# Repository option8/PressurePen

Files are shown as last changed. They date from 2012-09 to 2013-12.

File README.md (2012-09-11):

PressurePen
===========

Documentation and instructions for the open source hardware PressurePen project. The PressurePen is a pressure sensitive stylus for iPad and Android tablets that connects via a standard audio jack.

From FreedomDefined.org:

	Open source hardware is hardware whose design is made publicly available so that anyone can study, modify, distribute, make, and sell the design or hardware based on that design.

All hardware and specifications of the PressurePen are licensed under the TAPR OHL (see tapr.org/OHL). In summary, the license states:

	You may modify the documentation and make products based upon it.
	You may use products for any legal purpose without limitation.
	You may distribute unmodified documentation, but you must include the complete package as you received it.
	You may distribute products you make to third parties, if you either include the documentation on which the product is based, or make it available without charge for at least three years to anyone who requests it.
	You may distribute modified documentation or products based on it, if you:
	Include those modifications, following the requirements stated below.
	Attempt to send the modified documentation by email to any of the developers who have provided their email address. This is a good faith obligation -- if the email fails, you need do nothing more and may go on with your distribution.
	License your modifications under the OHL.

The full license text is here: http://www.tapr.org/TAPR_Open_Hardware_License_v1.0.txt

For 3D parts, see:
	http://www.thingiverse.com/option8
	
For sample application code, see:
	https://github.com/option8/PressurePaint
	
To order a kit or complete PressurePen, go to:
	http://pressurepen.us

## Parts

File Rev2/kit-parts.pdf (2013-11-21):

## For assembly instructions, go to https://www.tindie.com/products/option8/pressurepen-kit/

## These parts are included in your PressurePen Hacker Edition kit:

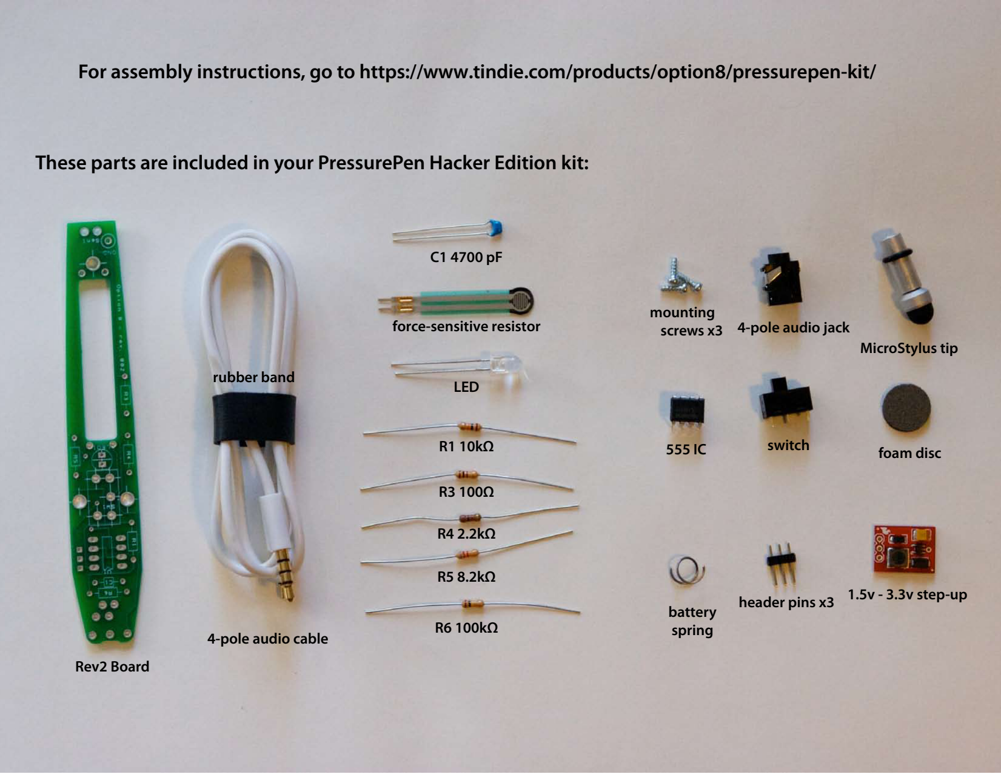
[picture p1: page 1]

Rev2 Board

switch

4-pole audio jack

mounting
screws x3
MicroStylus tip

foam disc

header pins x3 battery
spring 4-pole audio cable

rubber band

1.5v - 3.3v step-up

R1 10kΩ | 555 IC

R3 100Ω

R4 2.2kΩ

R5 8.2kΩ

R6 100kΩ

C1 4700 pF

LED

force-sensitive resistor

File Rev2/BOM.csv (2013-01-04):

Digi-Key Part Number | Description | Quantity | Manufacturer | Manufacturer Part Number
SW101-ND | SWITCH SLIDE SPDT 0.5A BLACK | 1 | CW INDUSTRIES | G-107-0513
CP-43514-ND | CONN 3.5MM AUDIO JACK 4 COND PCB | 1 | CUI INC | SJ-43514
1027-1000-ND | SENSOR FSR400 0.2" CIRC W/TAB | 1 | INTERLINK ELECTRONICS | 30-49649
296-1857-5-ND | IC OSC MONO TIMING 2.1MHZ 8-DIP | 1 | TEXAS INSTRUMENTS | TLC555CP
754-1273-ND | LED SS 5MM 568NM GREEN WATER CLR | 1 | KINGBRIGHT CORP | WP7113SGC
490-3844-ND | CAP CER 4700PF 50V 10% RADIAL | 1 | MURATA ELECTRONICS | RPER71H472K2P1A03B
8.2KQBK-ND | RES 8.2K OHM 1/4W 5% CARBON FILM | 1 | YAGEO | CFR-25JB-52-8K2
10KQBK-ND | RES 10K OHM 1/4W 5% CARBON FILM | 1 | YAGEO | CFR-25JB-52-10K
100KQBK-ND | RES 100K OHM 1/4W 5% CARBON FILM | 1 | YAGEO | CFR-25JB-52-100K
2.2KQBK-ND | RES 2.2K OHM 1/4W 5% CARBON FILM | 1 | YAGEO | CFR-25JB-52-2K2
100QBK-ND | RES 100 OHM 1/4W 5% CARBON FILM | 1 | YAGEO | CFR-25JB-52-100R
3429K-ND | SPACER RND #6SCREW .625"L ALUM | 1 | KEYSTONE ELECTRONICS | 3429
McMaster Carr Part Number
99397A314 | 6mm Torx (T5) M2 size screws | 3
92510A446 | Aluminum Unthreaded Spacer 1/4" OD, 5/8" Length, #6 Screw Size – ALT FOR DIGIKEY PART ABOVE | 1
SparkFun Part Number
PRT-10967 | NCP1402-3.3V Step-Up Breakout | 1
MicroStylus
 | MicroStylus Jack | 1
Amazon Supply
B005282S4G | 001-1/2 Buna-N O-Ring, 70A Durometer, Round, Black, 1/16" ID, 1/8" OD, 1/32" Width (Pack of 100) | 1
B001D8A3IM | 006 EPDM O-Ring, 70A Durometer, Black, 1/8" ID, 1/4" OD, 1/16" Width (Pack of 100) | 1
B005KUFNCK | Music Wire Compression Spring, Steel, Inch, 0.30" OD, 0.03" Wire Size | 1
Misc
 | conductive silicone foam .0625'' thickness | .5'' circle | Rogers Corp | EC2130
 | Header Pins, .1'' pitch, 11.5mm length | 3
 | Rubber band, 1'' x .5'' x .04'' | 1 | Aero Rubber Co
 | 4-pole 3.5mm audio cable, male-male | 1
 | Double-sided tape
 | Lead-free solder

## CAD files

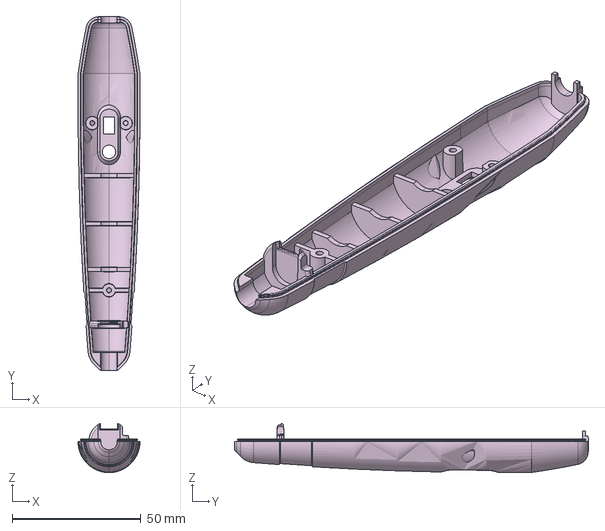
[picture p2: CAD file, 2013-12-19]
Rev2/shell/OP8_body_r12c_AA-Final.stp
24.1 x 137.6 x 19.2 mm

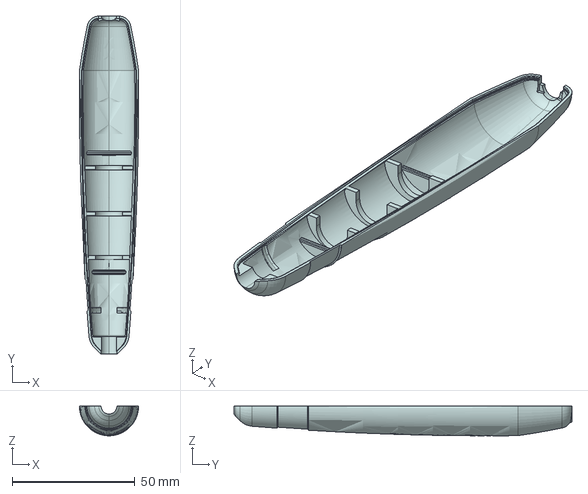
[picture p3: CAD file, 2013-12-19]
Rev2/shell/OP8_body_r12c_AB-Final.stp
24.0 x 137.5 x 12.1 mm

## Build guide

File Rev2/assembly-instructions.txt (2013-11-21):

Kit assembly instructions:

Open package and check contents. 

Last edit: 10.24.2012

1: Step-up board

For the following steps, you will need:
	soldering iron
	solder (preferably lead-free)
	
Locate the header pins (3) and 1.5v-3.3v step-up board (1).

With the flat side of the step-up board (the side with the OSHW logo) facing down, insert the short end of the header pins into the 3 holes.

Using a third hand, alligator clip or hemostat, hold the pins in place and flip the board over. Solder the pins in place as shown.

Set the step-up board aside.

2: Battery clips

For the following steps, you will need:
	soldering iron
	wire snips
	needle-nosed pliers
	
Locate the battery spring. 

With wire snips, cut the spring into two pieces as shown. You should be left with one spring with about one full loop, and a slightly longer spring.

You will be working on both sides of the PCB during assembly. The side with the resistor locations printed on it will be referred to as the “resistor side”, the other side, with “AAA” printed on it will be the “battery side”.

Looking at the “resistor” side of the board, thread the longer spring through the negative/ground holes. The negative end of the battery cutout is near the narrower end of the board. Repeat with the smaller spring and the positive end of the battery cutout. 

Before you solder these in place, test your fit with a AAA battery (not included). It should fit snugly between the springs and be held there by the tension on them on the “battery” side of the board. It may be necessary to remove another loop of make some bends in the springs to fit. The battery will sit on top of the cutout, on the battery side of the board. Once you're happy with the fit, solder the springs in place.

Turn the board over and clip any length of spring that pokes through. This may interfere with other components, or with assembly later.

3: Resistors

For the following steps, you will need:
	soldering iron
	wire snips
	alligator clips, hemostat, "third hand"
	tape
	double-sided tape

Locate the five resistors in your kit. You should have:
R1 10kΩ – brown-black-orange
R3 100Ω – brown-black-brown
R4 2.2kΩ – red-red-red
R5 8.2kΩ – grey-red-red*
R6 100kΩ – brown-black-yellow
(on the Rev2 board, there is no R2)

Bend the leads on the resistor, and thread them through the hole, so the body of the resistor is snug against the resistor side of the board. There is no polarity to these, so they can go in either direction. It helps to bend the leads outward again once you thread them through the hole, to hold the resistor in place while you solder it from the other side of the board.

Solder the leads to the board. Snip the extra length off. Save one of the leads for a later step. The others can be discarded.

Repeat with all five resistors.

* The 8.2kΩ resistor connects in-line with the LED. This reduces the brightness of the LED and its drain on the battery. If you desire a brighter indicator, you can replace the 8.2kΩ resistor with one of a smaller value.
4: Capacitor

Locate the capacitor in your kit. It's the small, blue thing that's not a resistor and not an LED.

As with the resistors, bend the leads of the capacitor to fit through the holes in the board and solder in place. Again, this capacitor has no polarity, so it can go in either direction.

5: LED

Locate the LED in your kit. LEDs have a specific polarity, so notice the length of the leads. The shorter leg corresponds with a flat spot on the side of the LED base. The shorter leg and flat side should line up with the flat side of the LED label on the board. Thread the legs through and double-check that the flat side of the LED lines up with the flat side of the label. The LED should also be snug to the board itself, or it may interfere with the shell when assembled.

Solder the leads to the board. Snip off the extra length and discard.

6: Switch

Locate the switch in your kit.

The switch will only fit on the board in one direction. On the Rev2 board, there will be seven holes, though the switch only needs five. The leads are short, so you may need to tape or clip the switch in place on the board while you solder the leads to the board from the battery side. The switch should also be snug to the board itself, or it may interfere with the shell when assembled.

Solder the five leads to the board. Be sure that these joints are solid, as the switch will be taking some mechanical stress from turning the PressurePen on and off.

7: 555 timer chip

Locate the 555 Integrated Circuit (IC) in your kit.

Notice that there's a small dot in one corner of the IC. This corresponds to pin #1. This dot should be on the same end of the IC as the notch in the printed diagram on the circuit board. Line up the dot and the notch and push the eight leads through the board. You may need to squeeze or bend the leads on the chip to fit through.

Before you solder, check to be sure the dot on the IC is nearest the wider end of the PressurePen board.

Once in place, you may again need to tape or clip the IC to the board to solder from the other side.

Solder the eight leads in place.

8: Audio jack

Locate the audio jack in your kit. 

Turn over the circuit board. You should now be looking at the battery side. At the wide end of the board, there is a small notch and seven holes marked CJ1. This will line up with the barrel of the audio jack, its four leads and small plastic posts. The jack should only fit one way on the board, the round part of the barrel sitting in the notch on the board.

Again, you may need to tape or clip the audio jack to the board to solder the leads from the other side. Be sure to make the jack snug to the board, or it may interfere with the fit of the plastic shell later.

Solder the four leads in place. Be sure that these joints are solid, as the jack will be taking some mechanical stress from plugging and unplugging the cable.

9: Step-up board 

Retrieve the 1.5v-3.3v step-up board you soldered header pins onto earlier. From the battery side of the PressurePen board, insert the three header pins into the holes marked "PL1". The red step-up board will "float" over the leads you soldered for the 555 chip, but should sit as close as possible to prevent interfering with the shell later.

Again, you may need to tape or clip the step-up board to the PressurePen board to solder the leads from the other side.

Solder the three leads from the other side.

At this point, you can test the board and your assembly by inserting an AAA battery between the spring leads you soldered earlier and flipping the switch to "on" - switch toward the LED. The LED should light up, indicating that at least some of your connections are working. Don't worry if the LED is dim – this is designed to maximize the battery life of the PressurePen. If you desire a brighter LED, see the alternate instructions above.

10: Ground wire

Locate one of the resistor or LED leads you set aside earlier in step 3. With the battery side of the board facing you, insert the lead into the small hole marked “GND” near the sensor end of the board. Solder the lead in place, so that a length of the wire extends above the board.

11: Force-sensitive resistor

Locate the force-sensitive resistor FSR from your kit. This looks like a small plastic ribbon with a circle on one end and two small leads on the other.

The FSR is fairly delicate, so be careful when handling it not to crimp or bend it too much. Being made of plastic, it is also liable to melt if you apply too much heat. For this reason, it's best to use an alligator clip or hemostat clipped across the ribbon where the leads are attached, to act as a heat sink as well as hold the FSR in place while soldering.

From the battery side of the board, insert the two leads of the FSR into the two holes marked "Sen1". Acting quickly so as not to melt the plastic of the FSR, solder the leads in place from the other side of the board. The sensor should extend up from the battery side of the board as shown. It doesn't matter which direction the sensor itself faces, since it measures force from both sides.

From this point on, you will need your PressurePen plastic shell. If you haven't already, you can order one from Shapeways - http://www.shapeways.com/shops/pressurepen - or fire up a 3D printer and download the STL files to print your own from Thingiverse - http://thingiverse.com/option8/
11: Assembly

For the following steps, you will need:
	PressurePen plastic shell*
	double-sided tape
	Torx T5 screwdriver

Place the board in the back half of the shell – the half with cutouts for the switch and LED – with the battery side facing up. The switch and LED should thread through the holes in the shell. If they don't go through smoothly, you may need to sand or file the openings for a clean fit.

With a T5 screwdriver, fasten the board to the shell with the three screws.

Cut a small strip of double-sided tape. This should be the thin, transparent type of tape, not foam tape. Place the tape either inside the indentation for the sensor in the tip of the shell, or on the sensor itself. Carefully bend the FSR over so that the round end fits into the indention in the tip of the shell as shown. Press the sensor firmly into the indent, making sure that the sensor is centered in its housing. Carefully fold or trim the excess tape out of the way.

Locate the small foam disc in your kit. Fit this over the sensor in the cavity in the tip of the shell. Press it down firmly, to press the sensor into its housing and the tape applied earlier.

Bend the grounding wire – the metal lead soldered into the GND hole – toward the stylus tip so that it threads through the small gap in the wall. Press the wire firmly into the foam disc to help keep the disc in place and ground the tip assembly. Cut or bend excess length of the wire out of the way so that it doesn't interfere with the sensor. 

Carefully bend the base of the sensor down parallel with the board toward the battery, as shown. This will ensure that the sensor doesn't interfere with the shell once it is assembled.

12: Assemble the conductive MicroStylus tip.

The MicroStylus tip should have a small o-ring around the shaft, secured in an indent. If the o-ring has migrated, move it back into place. The MicroStylus fits snugly into the stylus insert. There may be some resistance, so press firmly. The stylus tip and insert should snap together, securing the tip in place.

The stylus insert should have an o-ring around it, kept in place by friction and not in an indent. Snap the assembled stylus tip into the shell and adjust the o-ring so that the tip is secured inside the stylus housing, and the end is just against the sensor.

Depending on the source of your printed shell, you may need to sand or file the inside of the tip housing so that the MicroStylus tip moves freely. This is essential to the stylus working properly. Fine grit sandpaper works well, rolled into a tube and worked back and forth in the cutout.

13: Final assembly

Insert a single AAA battery between the contacts.

Snap the two halves of the shell together, back end first. The front half of the shell has a hole that fits around the audio jack on the board, and holds the back end of the PressurePen together. Wrap the rubber retaining band around the tip end and fit it into the indent. Your PressurePen should be ready to use.

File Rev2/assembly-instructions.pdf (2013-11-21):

### Kit assembly instructions:

Open package and check contents. See http://pressurepen.us/pages/instructions for updated parts list and errata to this document.

Last edit: 10.24.2012

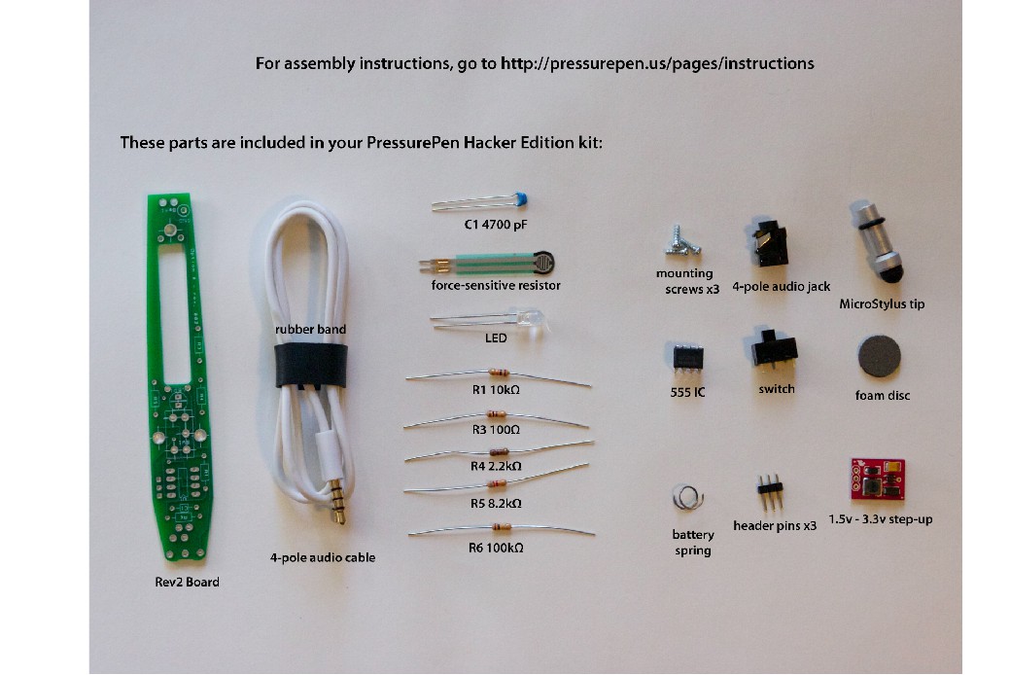
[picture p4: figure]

1: Step-up board

For the following steps, you will need:
soldering iron
solder (preferably lead-free)

Locate the header pins (3) and 1.5v-3.3v step-up board (1).

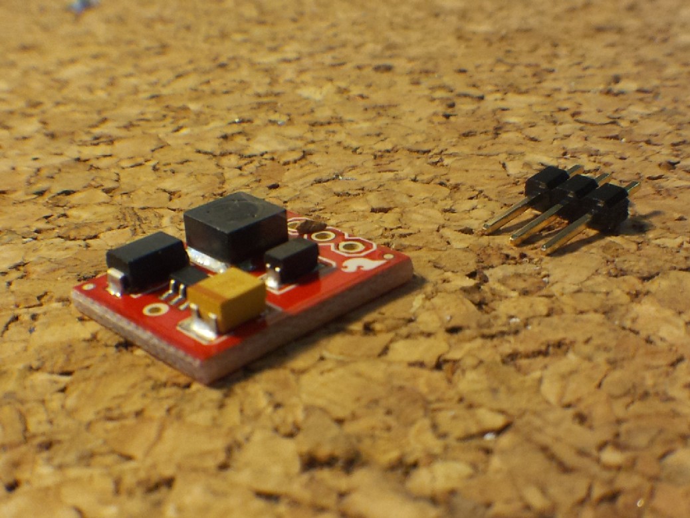
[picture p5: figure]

With the 'at side of the step-up board (the side with the OSHW logo) facing down, insert the short end of the header pins into the 3 holes.

Using a third hand, alligator clip or hemostat, hold the pins in place and 'ip the board over. Solder the pins in place as shown.

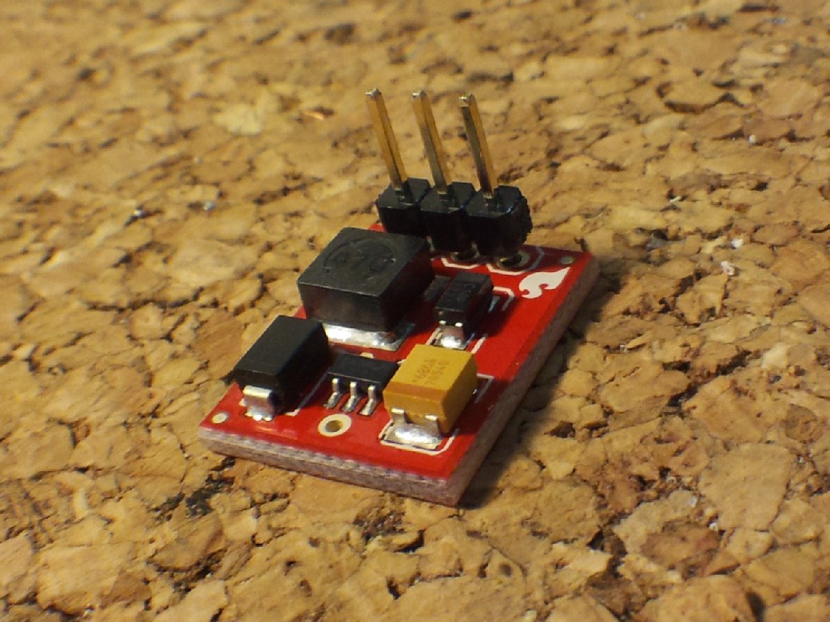
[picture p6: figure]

Set the step-up board aside.

2: Battery clips

For the following steps, you will need: soldering iron
wire snips
needle-nosed pliers

Locate the battery spring.

With wire snips, cut the spring into two pieces as shown. You should be left with one spring with about one full loop, and a slightly longer spring.

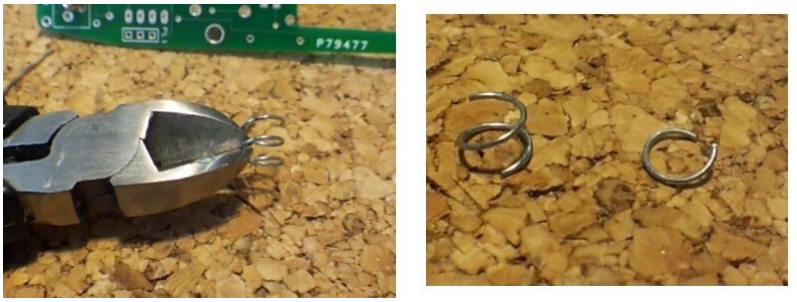
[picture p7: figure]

You will be working on both sides of the PCB during assembly. The side with the resistor locations printed on it will be referred to as the “resistor side”, the other side, with “AAA” printed on it will be the “battery side”.

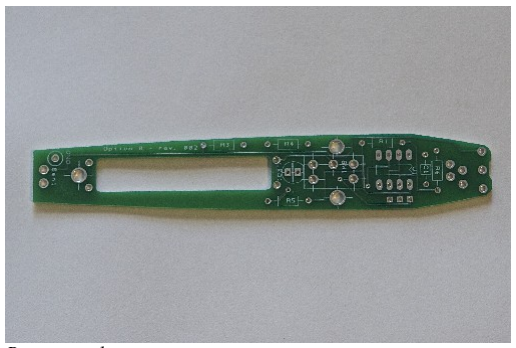
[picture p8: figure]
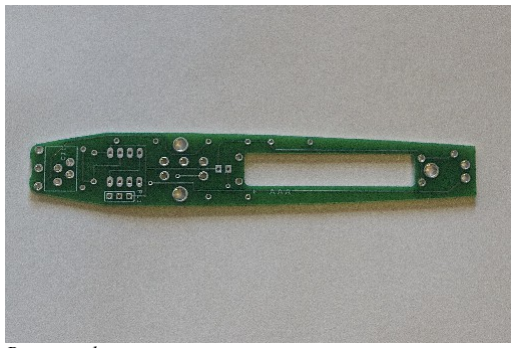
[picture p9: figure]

Looking at the “resistor” side of the board, thread the longer spring through the negative/ground holes. The negative end of the battery cutout is near the narrower end of the board. Repeat with the smaller spring and the positive end of the battery cutout.

Before you solder these in place, test your 3t with a AAA battery (not included). It should 3t snugly between the springs and be held there by the tension on them on the “battery” side of the board. It may be necessary to remove another loop of make some bends in the springs to 3t. The battery will sit on top of the cutout, on the battery side of the board. Once you're happy with the 3t, solder the springs in place.

Resistor side | Battery side

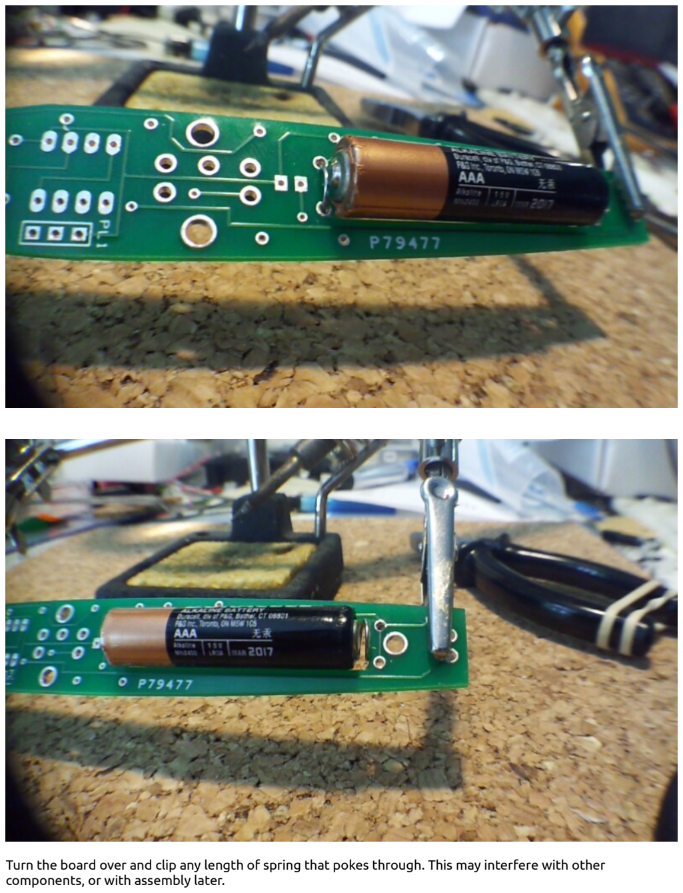
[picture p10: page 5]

Turn the board over and clip any length of spring that pokes through. This may interfere with other components, or with assembly later.

3: Resistors

For the following steps, you will need: soldering iron
wire snips
alligator clips, hemostat, "third hand"
tape
double-sided tape

Locate the 3ve resistors in your kit. You should have: R1 10kΩ – brown-black-orange
R3 100Ω – brown-black-brown
R4 2.2kΩ – red-red-red
R5 8.2kΩ – grey-red-red*
R6 100kΩ – brown-black-yellow
(on the Rev2 board, there is no R2)

Bend the leads on the resistor, and thread them through the hole, so the body of the resistor is snug against the resistor side of the board. There is no polarity to these, so they can go in either direction. It helps to bend the leads outward again once you thread them through the hole, to hold the resistor in place while you solder it from the other side of the board.

Solder the leads to the board. Snip the extra length o@. Save one of the leads for a later step. The others can be discarded.

Repeat with all 3ve resistors.

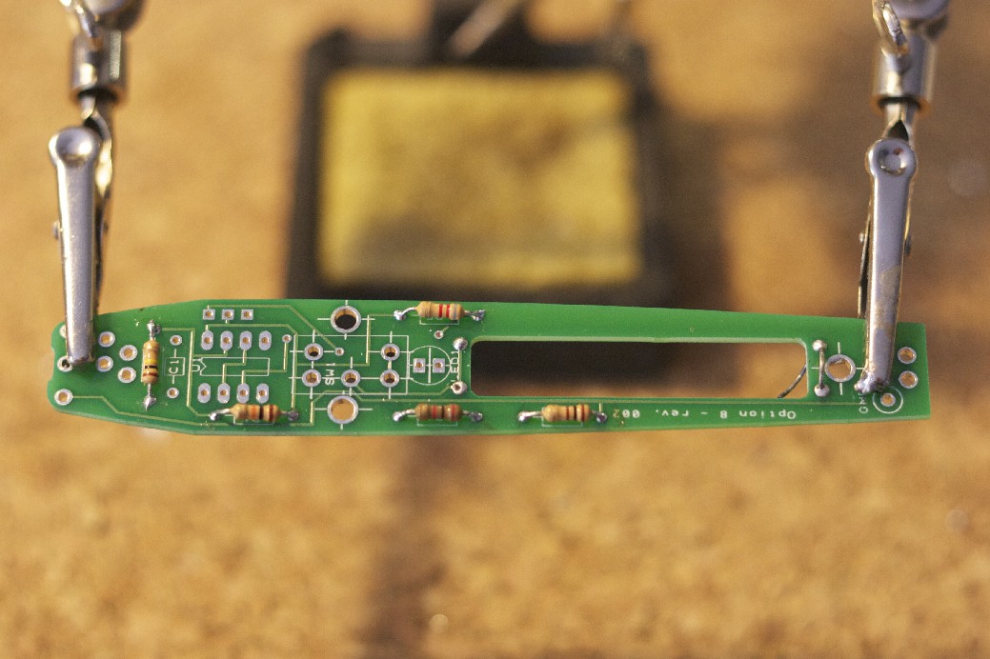
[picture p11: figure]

* The 8.2kΩ resistor connects in-line with the LED. This reduces the brightness of the LED and its drain on the battery. If you desire a brighter indicator, you can replace the 8.2kΩ resistor with one of a smaller value.

4: Capacitor

Locate the capacitor in your kit. It's the small, blue thing that's not a resistor and not an LED.

As with the resistors, bend the leads of the capacitor to 3t through the holes in the board and solder in place. Again, this capacitor has no polarity, so it can go in either direction.

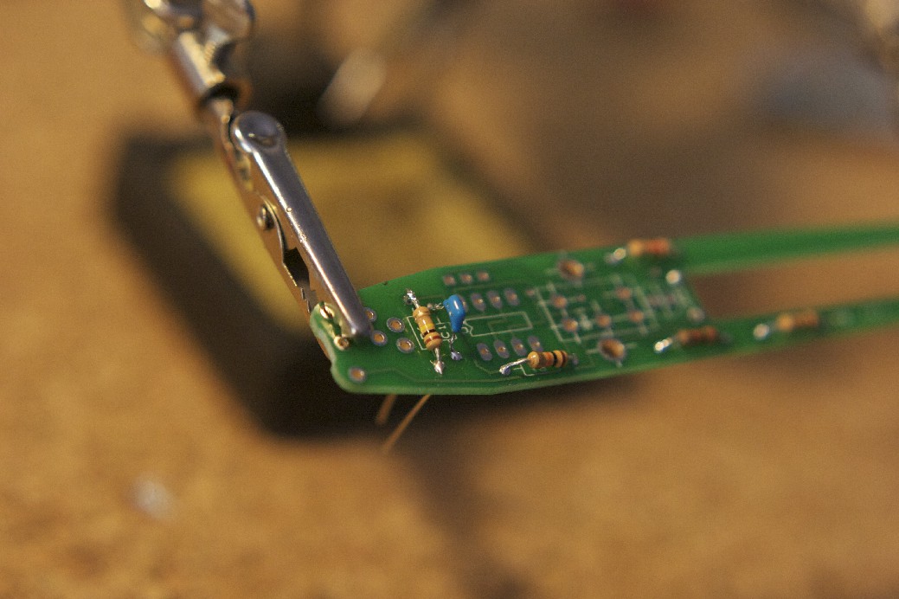
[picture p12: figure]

5: LED

Locate the LED in your kit. LEDs have a speci3c polarity, so notice the length of the leads. The shorter leg corresponds with a 'at spot on the side of the LED base. The shorter leg and 'at side should line up with the 'at side of the LED label on the board. Thread the legs through and double-check that the 'at side of the LED lines up with the 'at side of the label. The LED should also be snug to the board itself, or it may interfere with the shell when assembled.

Solder the leads to the board. Snip o@ the extra length and discard.

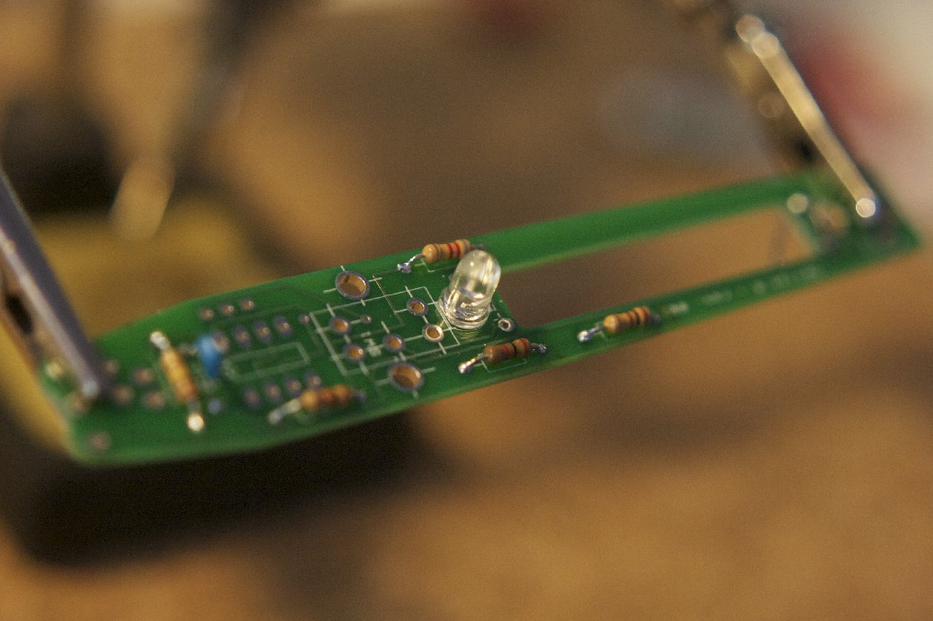
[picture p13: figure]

6: Switch

Locate the switch in your kit.

The switch will only 3t on the board in one direction. On the Rev2 board, there will be seven holes, though the switch only needs 3ve. The leads are short, so you may need to tape or clip the switch in place on the board while you solder the leads to the board from the battery side. The switch should also be snug to the board itself, or it may interfere with the shell when assembled.

Solder the 3ve leads to the board. Be sure that these joints are solid, as the switch will be taking some mechanical stress from turning the PressurePen on and o@.

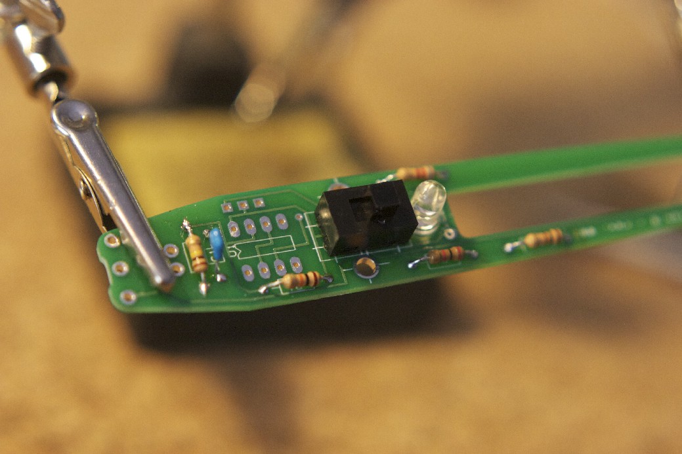
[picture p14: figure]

7: 555 timer chip

Locate the 555 Integrated Circuit (IC) in your kit.

Notice that there's a small dot in one corner of the IC. This corresponds to pin #1. This dot should be on the same end of the IC as the notch in the printed diagram on the circuit board. Line up the dot and the notch and push the eight leads through the board. You may need to squeeze or bend the leads on the chip to 3t through.

Before you solder, check to be sure the dot on the IC is nearest the wider end of the PressurePen board.

Once in place, you may again need to tape or clip the IC to the board to solder from the other side.

Solder the eight leads in place.

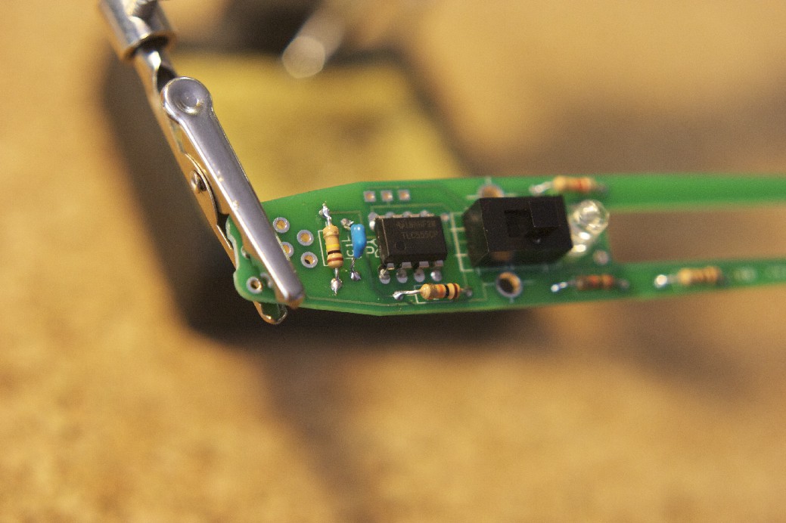
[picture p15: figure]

8: Audio jack

Locate the audio jack in your kit.

Turn over the circuit board. You should now be looking at the battery side. At the wide end of the board, there is a small notch and seven holes marked CJ1. This will line up with the barrel of the audio jack, its four leads and small plastic posts. The jack should only 3t one way on the board, the round part of the barrel sitting in the notch on the board.

Again, you may need to tape or clip the audio jack to the board to solder the leads from the other side. Be sure to make the jack snug to the board, or it may interfere with the 3t of the plastic shell later.

Solder the four leads in place. Be sure that these joints are solid, as the jack will be taking some mechanical stress from plugging and unplugging the cable.

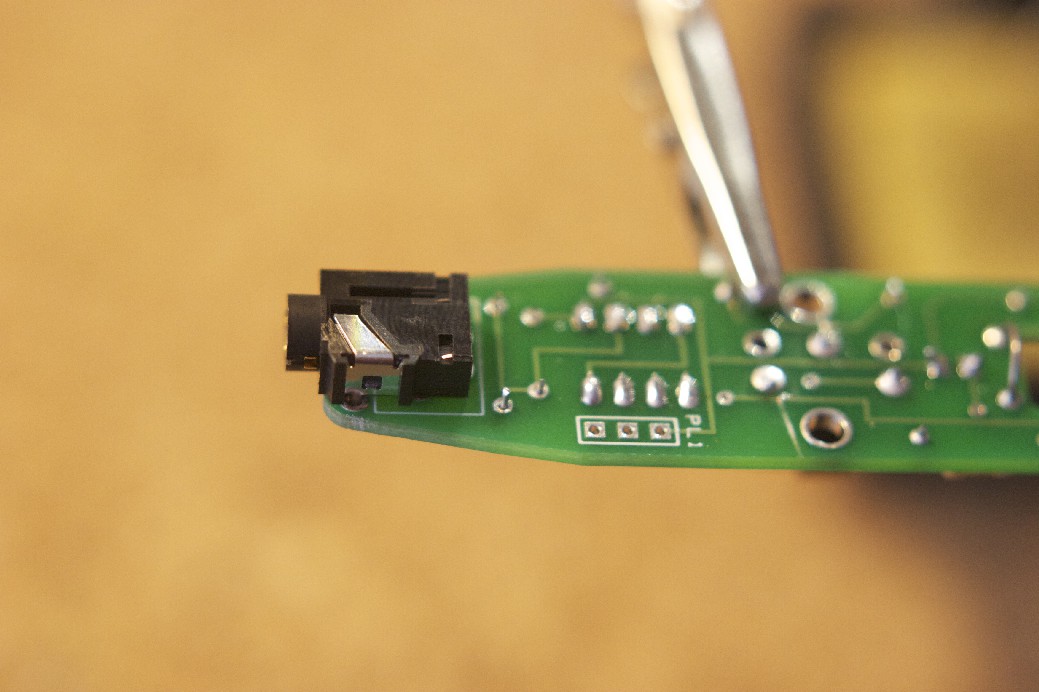
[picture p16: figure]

9: Step-up board

Retrieve the 1.5v-3.3v step-up board you soldered header pins onto earlier. From the battery side of the PressurePen board, insert the three header pins into the holes marked "PL1". The red step-up board will "'oat" over the leads you soldered for the 555 chip, but should sit as close as possible to prevent interfering with the shell later.

Again, you may need to tape or clip the step-up board to the PressurePen board to solder the leads from the other side.

Solder the three leads from the other side.

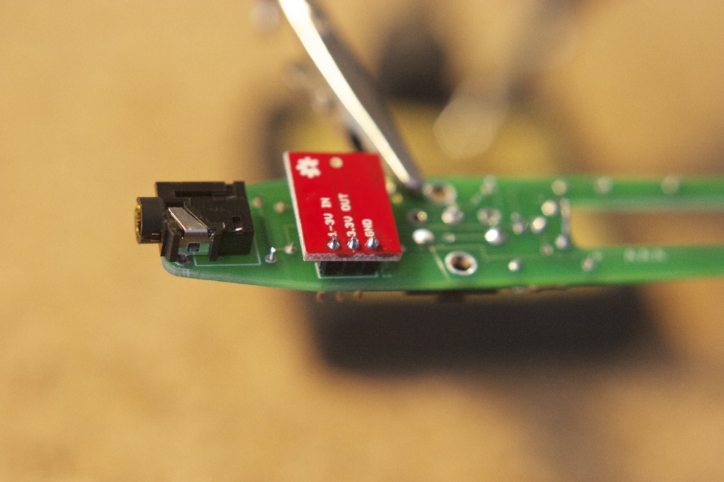
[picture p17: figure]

At this point, you can test the board and your assembly by inserting an AAA battery between the spring leads you soldered earlier and 'ipping the switch to "on" - switch toward the LED. The LED should light up, indicating that at least some of your connections are working. Don't worry if the LED is dim – this is designed to maximize the battery life of the PressurePen. If you desire a brighter LED, see the alternate instructions above.

10: Ground wire

Locate one of the resistor or LED leads you set aside earlier in step 3. With the battery side of the board facing you, insert the lead into the small hole marked “GND” near the sensor end of the board. Solder the lead in place, so that a length of the wire extends above the board.

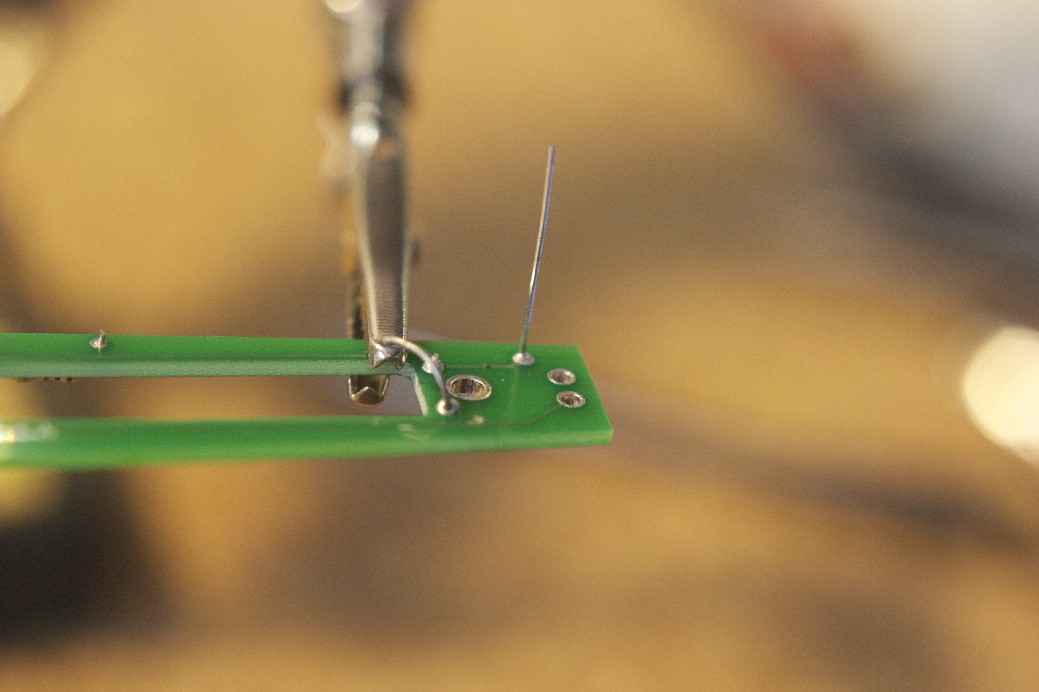
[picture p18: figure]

11: Force-sensitive resistor

Locate the force-sensitive resistor FSR from your kit. This looks like a small plastic ribbon with a circle on one end and two small leads on the other.

The FSR is fairly delicate, so be careful when handling it not to crimp or bend it too much. Being made of plastic, it is also liable to melt if you apply too much heat. For this reason, it's best to use an alligator clip or hemostat clipped across the ribbon where the leads are attached, to act as a heat sink as well as hold the FSR in place while soldering.

From the battery side of the board, insert the two leads of the FSR into the two holes marked "Sen1". Acting quickly so as not to melt the plastic of the FSR, solder the leads in place from the other side of the board. The sensor should extend up from the battery side of the board as shown. It doesn't matter which direction the sensor itself faces, since it measures force from both sides.

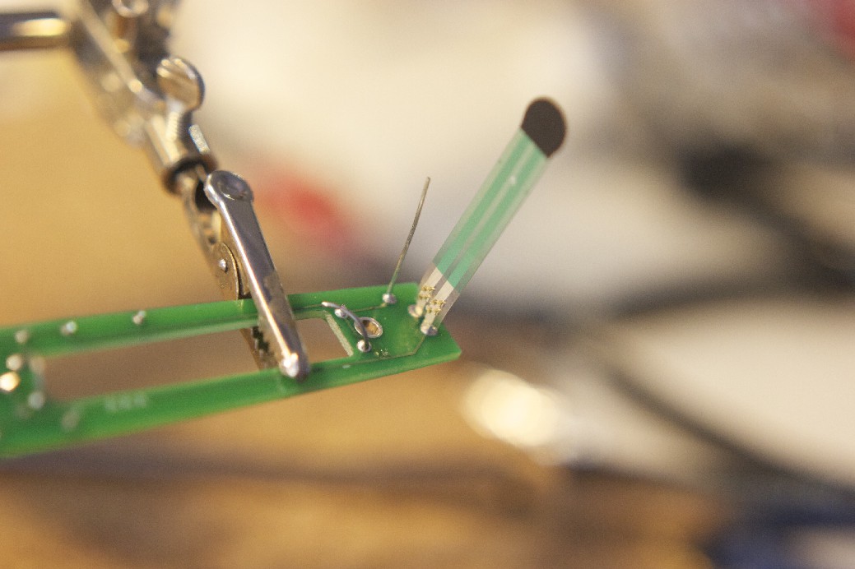
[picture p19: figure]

From this point on, you will need your PressurePen plastic shell. If you haven't already, you can order one from Shapeways - http://www.shapeways.com/shops/pressurepen - or ,re up a 3D printer and download the STL ,les to print your own from Thingiverse - http://thingiverse.com/option8/

11: Assembly

For the following steps, you will need: PressurePen plastic shell*
double-sided tape
Torx T5 screwdriver

Place the board in the back half of the shell – the half with cutouts for the switch and LED – with the battery side facing up. The switch and LED should thread through the holes in the shell. If they don't go through smoothly, you may need to sand or 3le the openings for a clean 3t.

With a T5 screwdriver, fasten the board to the shell with the three screws.

Cut a small strip of double-sided tape. This should be the thin, transparent type of tape, not foam tape. Place the tape either inside the indentation for the sensor in the tip of the shell, or on the sensor itself. Carefully bend the FSR over so that the round end 3ts into the indention in the tip of the shell as shown. Press the sensor 3rmly into the indent, making sure that the sensor is centered in its housing. Carefully fold or trim the excess tape out of the way.

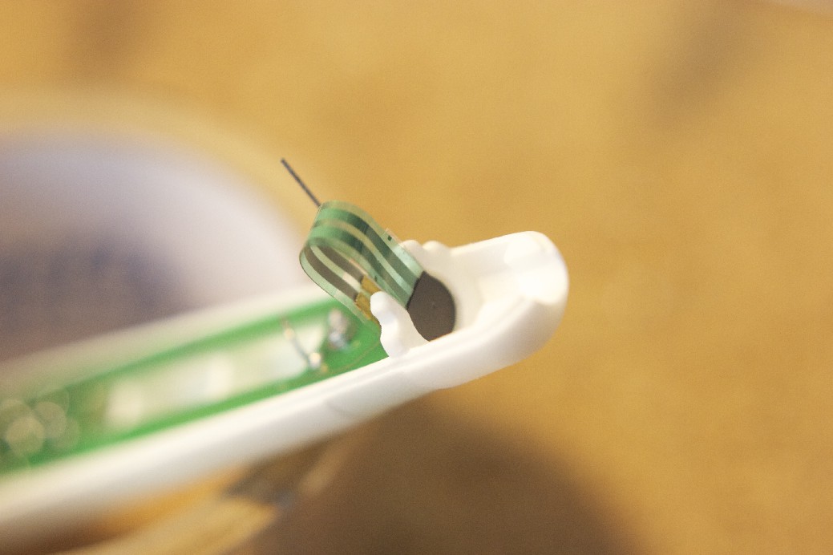
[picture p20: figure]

Locate the small foam disc in your kit. Fit this over the sensor in the cavity in the tip of the shell. Press it down 3rmly, to press the sensor into its housing and the tape applied earlier.

Bend the grounding wire – the metal lead soldered into the GND hole – toward the stylus tip so that it threads through the small gap in the wall. Press the wire 3rmly into the foam disc to help keep the disc in place and ground the tip assembly. Cut or bend excess length of the wire out of the way so that it doesn't interfere with the sensor.

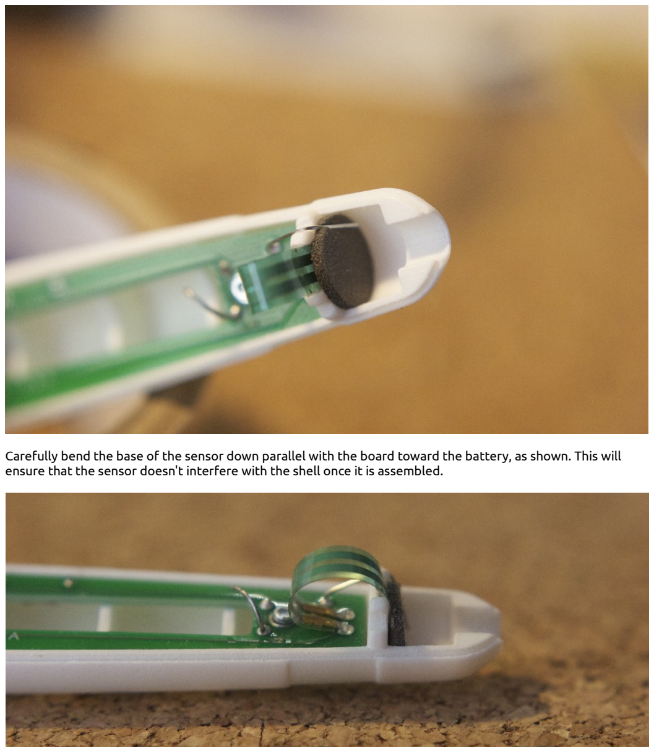
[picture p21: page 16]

Carefully bend the base of the sensor down parallel with the board toward the battery, as shown. This will ensure that the sensor doesn't interfere with the shell once it is assembled.

12: Assemble the conductive MicroStylus tip.

The MicroStylus tip should have a small o-ring around the shaft, secured in an indent. If the o-ring has migrated, move it back into place. The MicroStylus 3ts snugly into the stylus insert. There may be some resistance, so press 3rmly. The stylus tip and insert should snap together, securing the tip in place.

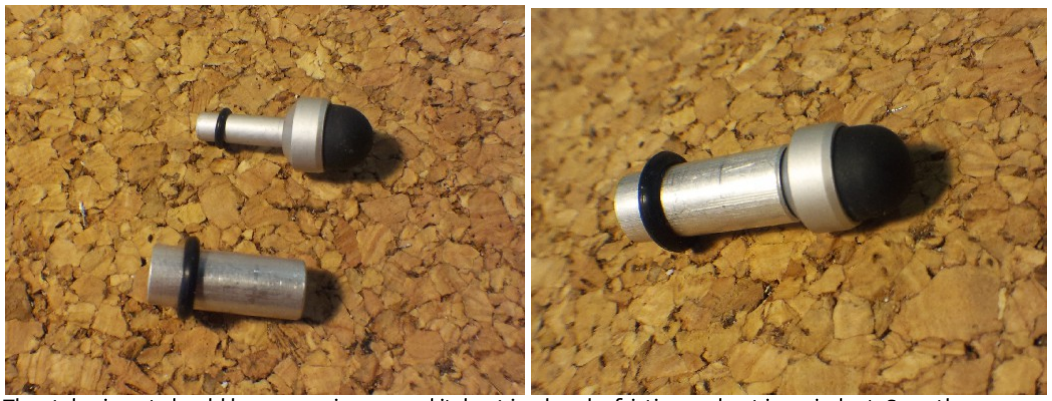
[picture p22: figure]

The stylus insert should have an o-ring around it, kept in place by friction and not in an indent. Snap the assembled stylus tip into the shell and adjust the o-ring so that the tip is secured inside the stylus housing, and the end is just against the sensor.

Depending on the source of your printed shell, you may need to sand or 3le the inside of the tip housing so that the MicroStylus tip moves freely. This is essential to the stylus working properly. Fine grit sandpaper works well, rolled into a tube and worked back and forth in the cutout.

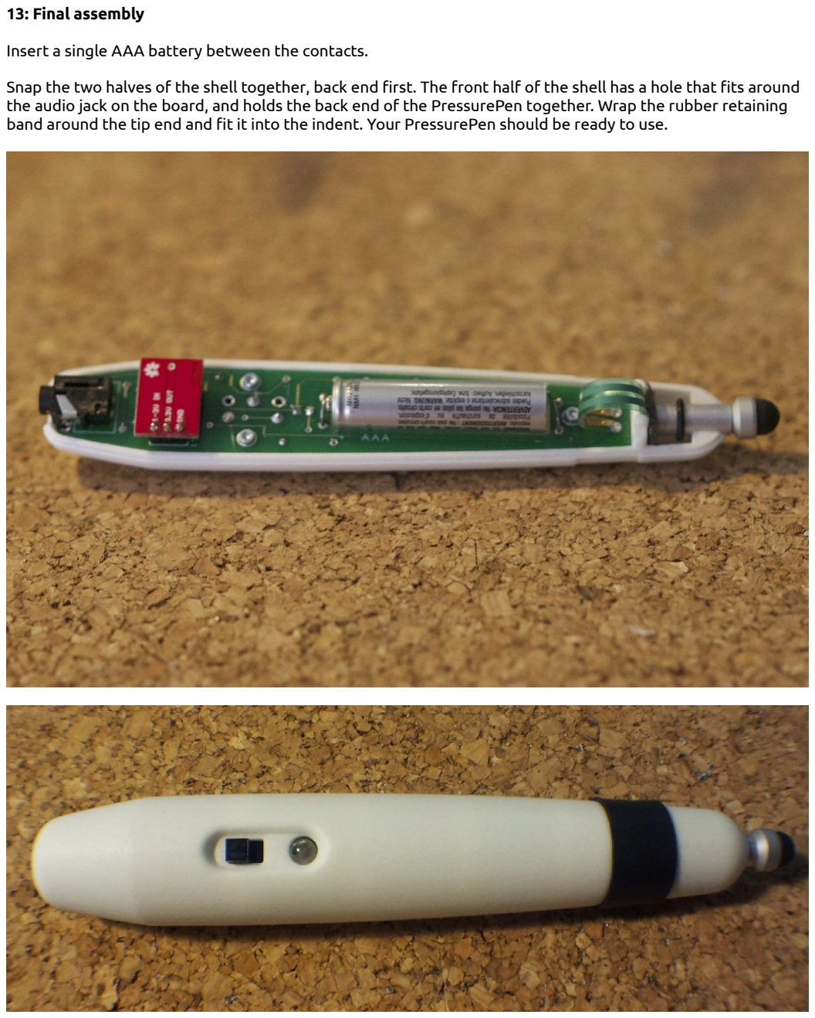
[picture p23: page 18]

13: Final assembly

Insert a single AAA battery between the contacts.

Snap the two halves of the shell together, back end 3rst. The front half of the shell has a hole that 3ts around the audio jack on the board, and holds the back end of the PressurePen together. Wrap the rubber retaining band around the tip end and 3t it into the indent. Your PressurePen should be ready to use.

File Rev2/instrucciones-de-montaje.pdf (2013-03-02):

Instrucciones de montaje del kit:

Abra | el | paquete | y | compruebe | que | está | completo. | Vea
http://pressurepen.us/pages/instructions para una lista de componentes y fe de erratas actualizadas de este documento.

Última edición: 28/02/2013

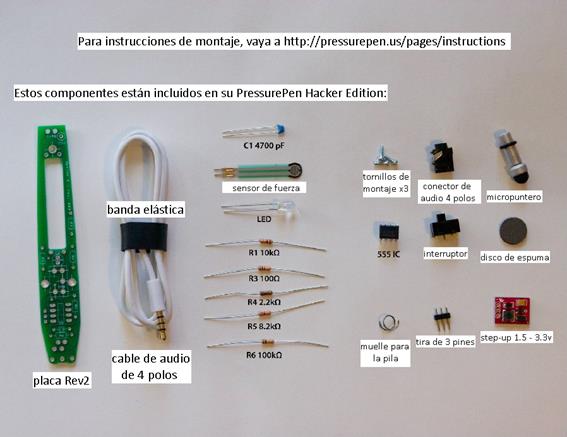
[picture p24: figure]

1: Conversor Step-up

Para los siguientes pasos, necesitara:

- Soldador
- Estaño (preferiblemente sin plomo)

Localice la tira pines (3) y el conversor Step-up de 1'5v a 3'3v (1).

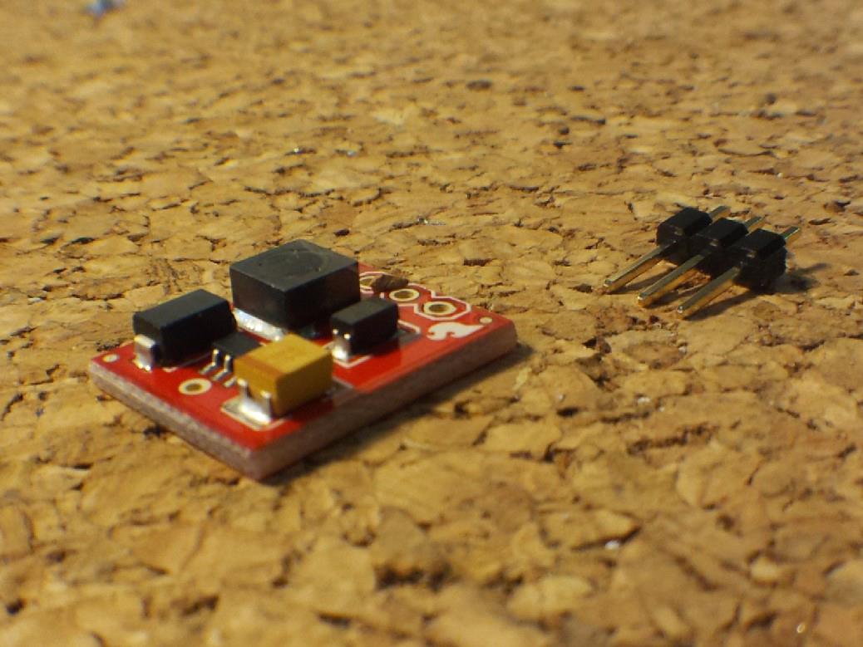
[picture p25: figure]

Con el lado plano de la placa Step-up (el lado con el logo de OSHW) mirando hacia abajo, inserte el extremo más corto de la tira de pines en los tres orificios.

Con la ayuda de una "tercera mano", un "cocodrilo" o un hemostato, sujete los pines en su lugar y dé la vuelta a la placa. Suelde los pines en su lugar como se muestra.

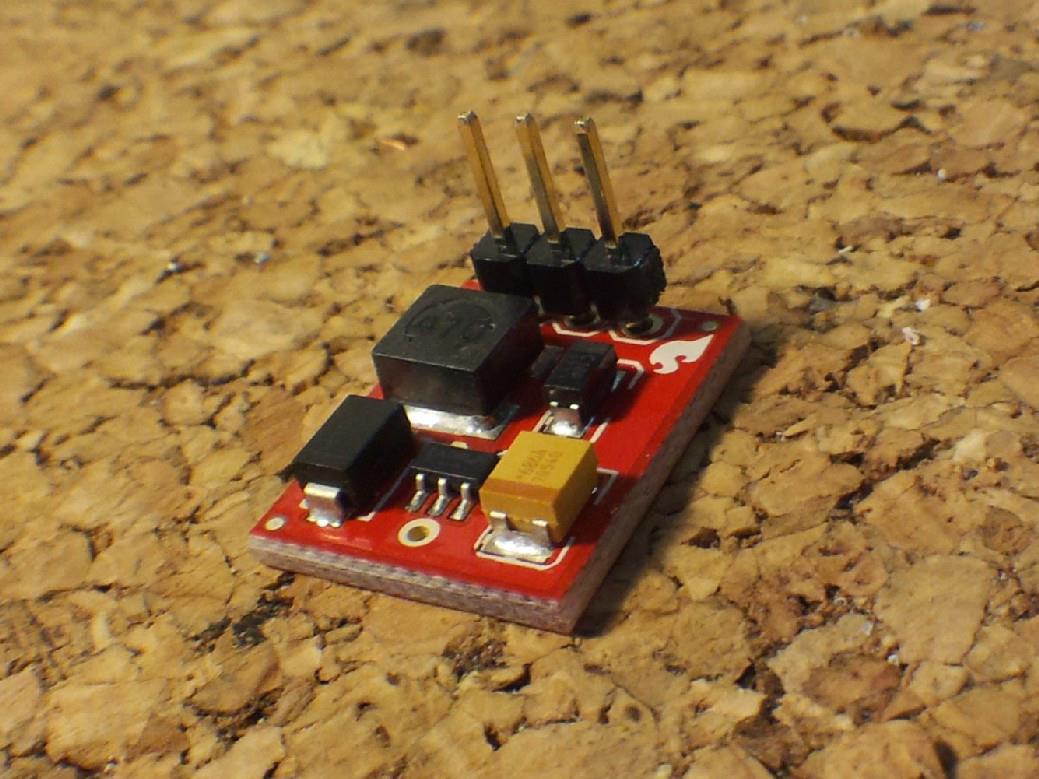
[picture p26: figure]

Aparte la placa de momento.

2: Clips para la pila

Para los siguientes pasos, necesitara:

- Soldador
- Pinza cortacables
- Pinzas

Localice el muelle para la pila.

Con las pinzas cortacables, corte el muelle en dos piezas como se muestra. Debiera quedarse con un muelle con aproximadamente una vuelta completa, y otro ligeramente más largo.

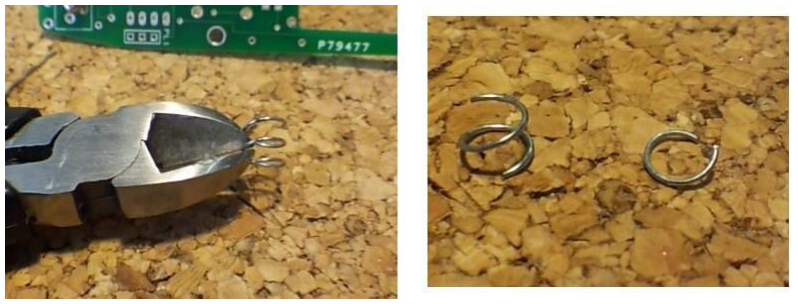
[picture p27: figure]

Tendrá que trabajar sobre ambas partes de la PCB durante el montaje. Me referiré a la cara con la impresión de la localización de las resistencias como la "cara de resistencias", y al otro lado, con las letras "AAA" impresas, como la "la cara de la pila".

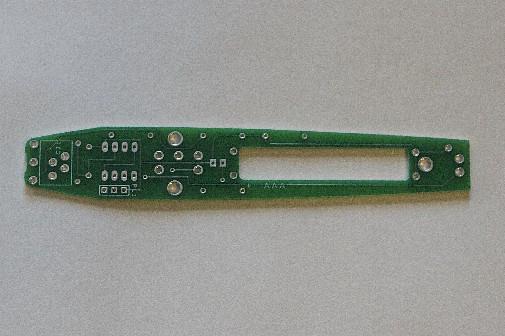
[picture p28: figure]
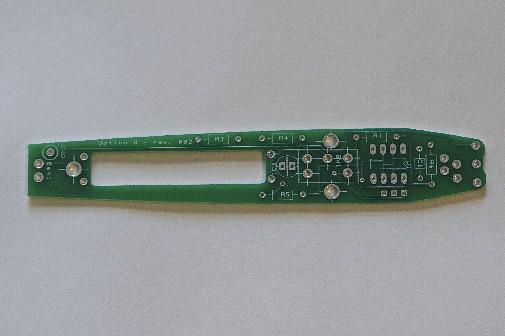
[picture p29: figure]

“Cara de resistencias” | “Cara de la pila”

Con la "cara de resistencias" mirando hacia usted, introduzca el muelle de mayor longitud por los orificios del polo negativo/tierra. El polo negativo en el orificio para la pila se corresponde con el extremo más estrecho de la placa. Repita este paso con el muelle más corto y el extremo positivo.

Antes de soldar los muelles, compruebe que una pila AAA (no incluida) se ajusta a los muelles y queda encajada en la "cara de la pila" de la placa. Puede ser necesario quitar alguna vuelta o realizar algún doblez sobre el muelle para que se ajuste. La pila quedará sobre el orificio, en la "cara de la pila". Una vez que considere adecuado el montaje, proceda a soldar los muelles.

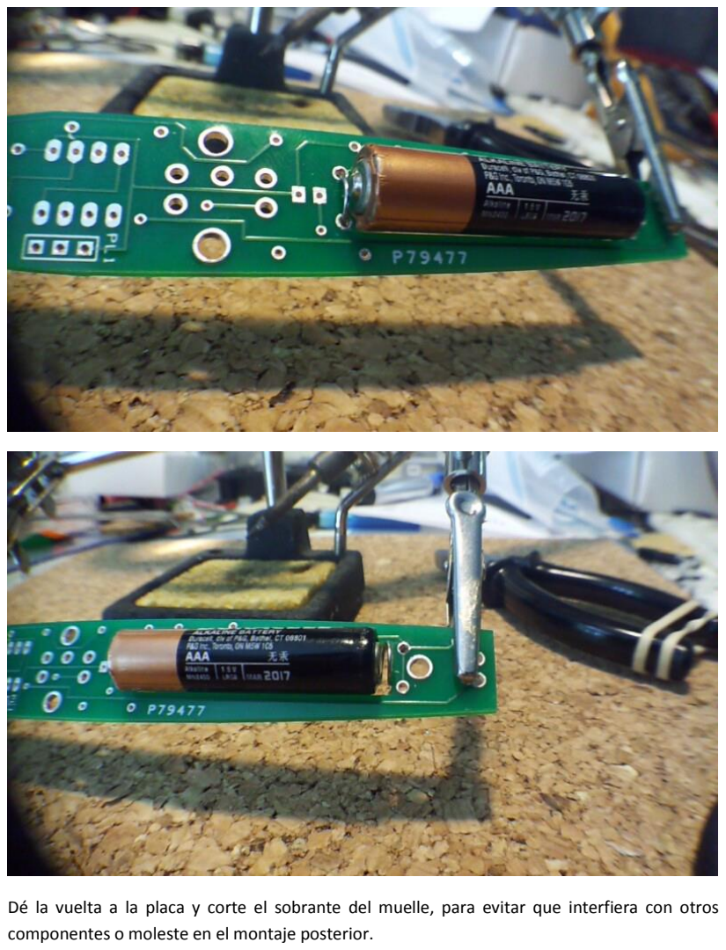
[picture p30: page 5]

Dé la vuelta a la placa y corte el sobrante del muelle, para evitar que interfiera con otros componentes o moleste en el montaje posterior.

3: Resistencias

Para los siguientes pasos, necesitara:

- Soldador
- Pinza cortacables
- "Cocodrilos", hemostato, "tercera mano"
- Cinta adhesiva
- Cinta adhesiva de doble cara

Localice las cinco resistencias. Debiera encontrar:

- R1 10kΩ – marrón-negro-naranja
- R3 100Ω – marrón-negro-marrón
- R4 2.2kΩ – rojo-rojo-rojo
- R5 8.2kΩ – gris-rojo-rojo*
- R6 100kΩ – marrón-negro-amarillo
- (R2 no existe en la placa Rev2)
Doble los terminales de la resistencia e introdúzcalos por el orificio de manera que la resistencia quede sobre y tocando la "cara de resistencias". Estos componentes carecen de polaridad por lo que pueden introducirse en cualquier dirección. Puede encontrar útil doblar los extremos de los terminales una vez introducidos por los orificios para que la resistencia quede fija a la hora de soldarla.

Suelde los terminales a la placa, y corte el sobrante. Guarde uno de los fragmentos cortados para un paso posterior, el resto pueden ser desechados. Repita este paso con las cinco resistencias restantes.

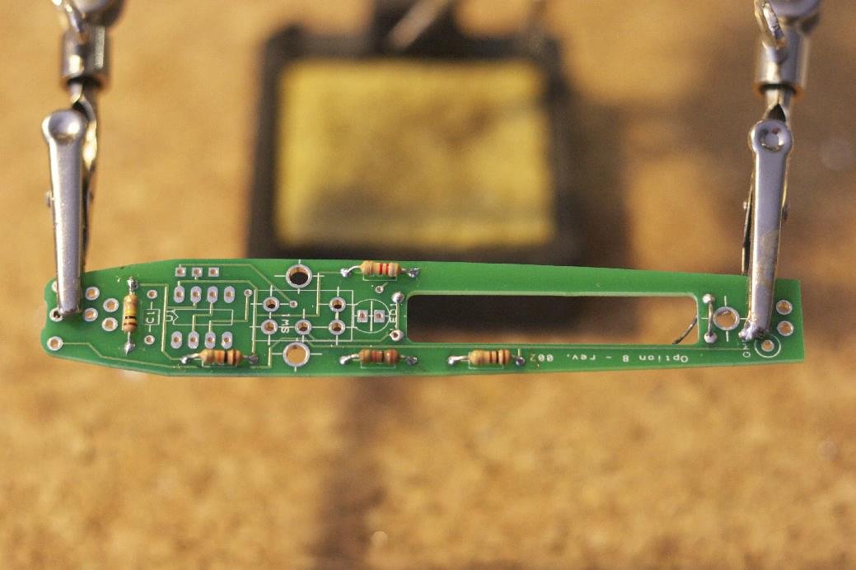
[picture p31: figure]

* La resistencia de 8.2kΩ se conecta en serie con el LED, para reducir el brillo y el consumo del mismo. Si desea un indicador más brillante, sustituya esta resistencia por una de un valor inferior.

4: Condensador

Localice el condensador. Es el componente de pequeño tamaño, azul, que no es ni una resistencia ni un LED.

Al igual que hizo con las resistencias, doble los terminales del condensador para que encajen los orificios de la placa, y suéldelo en su lugar. Este condensador tampoco tiene polaridad, por lo que puede ir en cualquier dirección.

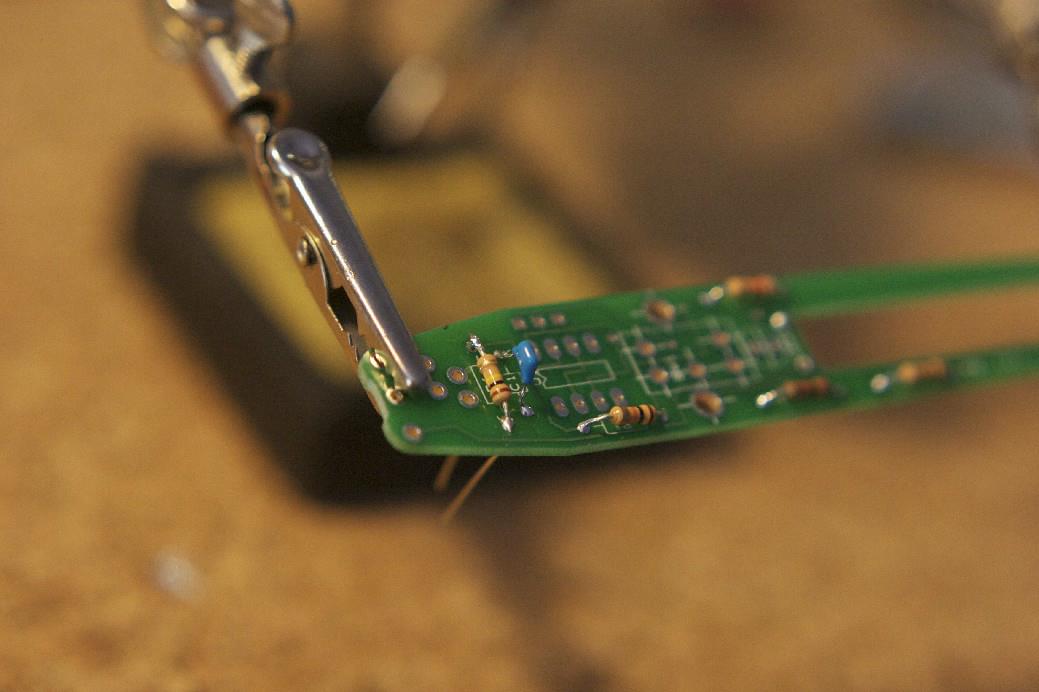
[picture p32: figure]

5: LED

Localice el LED. Los LEDs sí tienen polaridad, así que fíjese en la longitud de los terminales. La más corta corresponde con la zona aplanada en la base del cuerpo del LED. El terminal más corto y zona aplanada deben alinearse con la cara plana de la representación del LED en la placa. Introduzca los terminales del LED y compruebe que la zona plana coincide con la representación. El LED debe asimismo quedar pegado a la placa para que no impida el montaje posterior de la carcasa.

Suelde los terminales a la placa, y deshágase del sobrante.

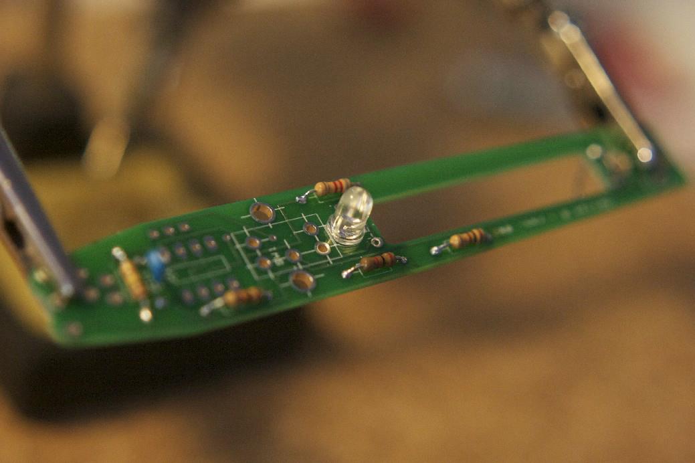
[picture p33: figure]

6: Interruptor

Localice el interruptor.

El interruptor sólo puede ser introducido en la placa en un sentido. En la placa Rev2, hay siete orificios, aunque sólo cinco son necesarios. Los terminales son cortos, por lo que deberá sujetar el componente a la placa mientras lo suelda desde la "cara de la pila". El interruptor también debe quedar pegado a la placa para no interferir en el posterior montaje de la carcasa.

Suelde los cinco terminales a la placa y asegúrese de que las soldaduras son sólidas, ya que también deben resistir el esfuerzo mecánico al que se verá sometido el interruptor al encender y apagar su PressurePen.

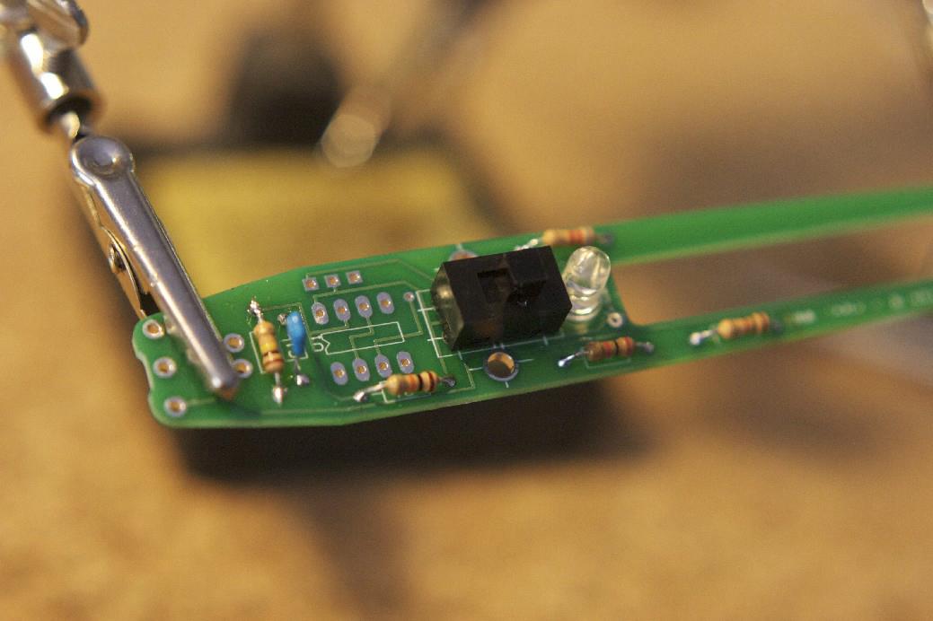
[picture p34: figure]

7: Circuito integrado 555

Localice el circuito integrado 555.

Fíjese en el pequeño punto de una de las esquinas del encapsulado. Este punto se corresponde con el pin 1. Este punto debe quedar en el mismo lado en el que la representación en la placa tiene una muesca. Alinee el punto y la muesca y presione las 8 paras del circuito por los orificios a tal efecto de la placa. Puede que tenga que oprimir o doblar los terminales para que el circuito encaje.

Antes de soldar compruebe que el punto en el encapsulado está más cerca del extremo más ancho de la placa.

Una vez en su sitio, puede que deba sujetar el circuito para poder soldar cómodamente desde el lado contrario de la placa.

Suelde los ocho terminales en su sitio.

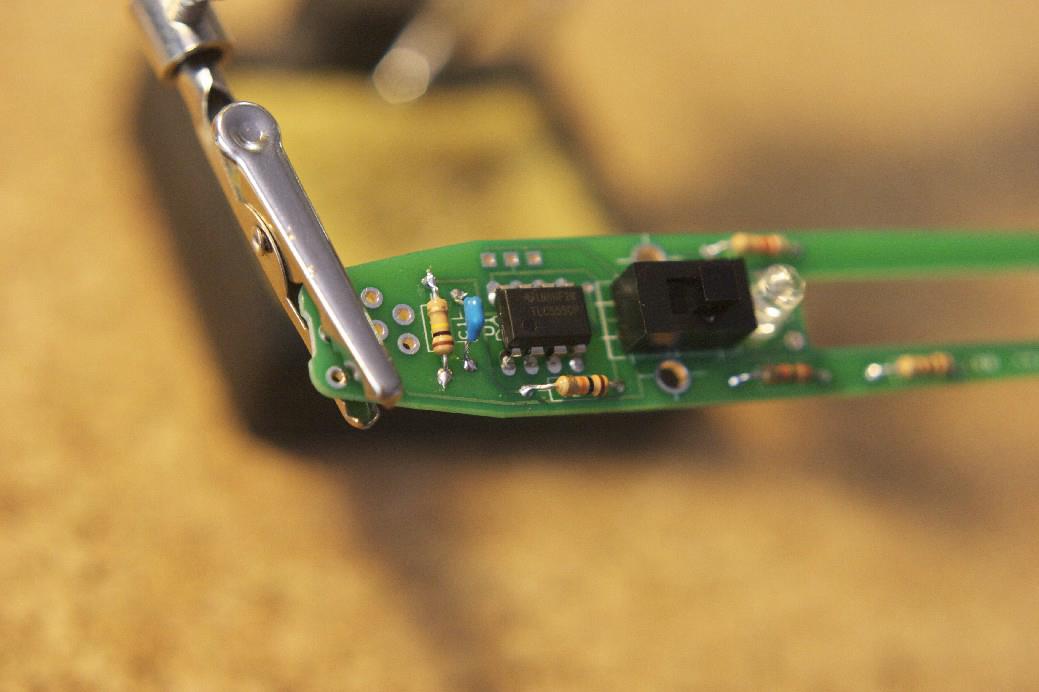
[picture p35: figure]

8: Conector de audio

Localice el conector de audio.

Dé la vuelta a la placa, de manera que la "cara de la pila" quede mirando hacia arriba. En el extremo ancho de la misma, hay una pequeña muesca y siete orificios marcados como CJ1. Deben alinearse con parte cilíndrica del conector, sus cinco terminales y los pequeños postes de plástico. El conector sólo encaja de una única manera en la placa, de manera que la parte cilíndrica del conector queda encajada en la muesca.

De nuevo puede que vea necesario fijar de alguna manera el componente a la placa mientras lo suelda. Asegúrese de que el conector queda pegado a la placa para que la carcasa de plástico encaje a la hora de montarla.

Suelde los cuatro cables. Asegúrese de que las soldaduras son sólidas ya que también sufrirán esfuerzo mecánico al introducir y extraer el cable.

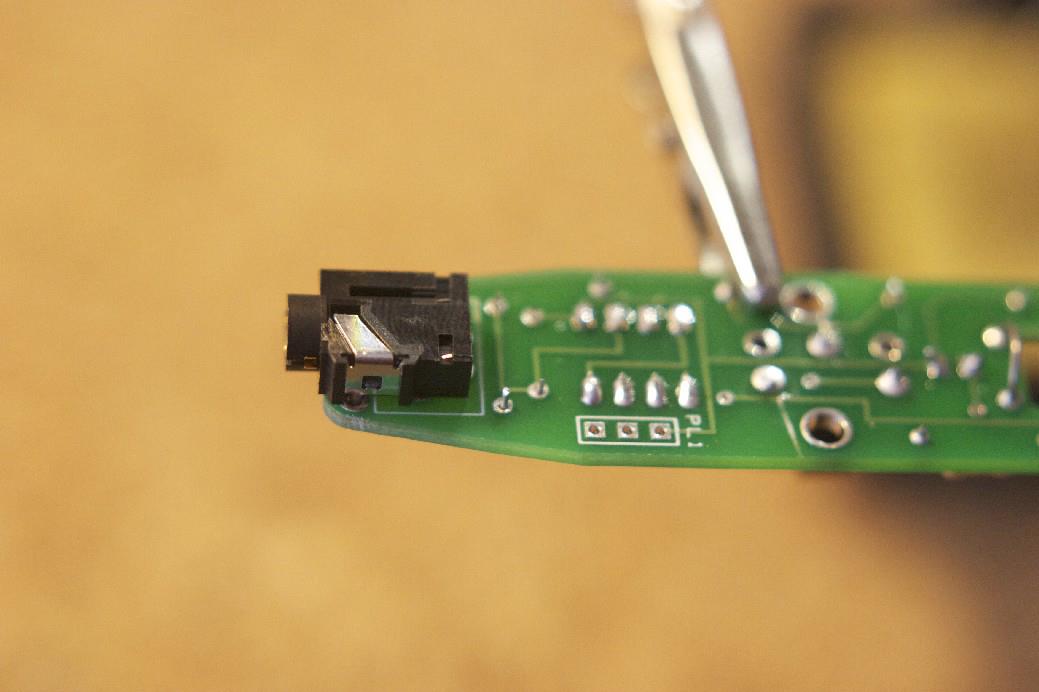
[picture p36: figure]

9: Conversor Step-up

Coja la placa a la que soldó la tira de tres pines. Desde la "cara de la pila" inserte los tres pines en los orificios marcados como "PL1". La placa quedará en el aire sobre las soldaduras de los terminales del 555, pero debe quedar lo más cerca posible de la placa para impedir que interfiera con el montaje final de la carcasa.

De nuevo puede que vea necesario fijar de alguna manera el componente a la placa mientras lo suelda.

Suelde los tres pines desde el lado opuesto.

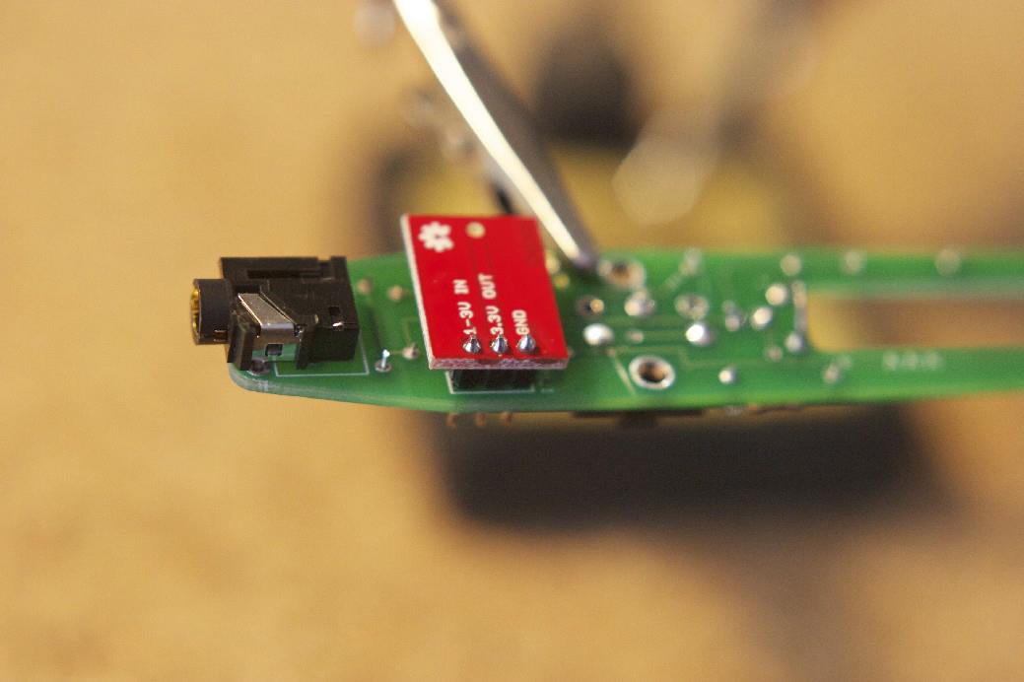
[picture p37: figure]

Llegados a este punto, puede comprobar el montaje insertando una pila AAA entre los muelles a tal efecto, y mover el interruptor a la posición de encendido (más cercano al LED). El LED debiera encenderse, indicando que al menos algunas de las conexiones funcionan. No se preocupe si la iluminación del LED es tenue, ya que el circuito ha sido diseñado para minimizar el consumo. Si desea que el brillo sea mayor, vea las indicaciones al respecto más arriba.

10: Cable de tierra

Coja el pedazo de terminal de resistencia que apartó en el paso 3. Con la "cara de la pila" mirando hacia usted, inserte el terminal en el orificio marcado como "GND" cerca del extremo de la placa más cercano al sensor. Suelde el terminal de manera que sobresalga de la placa.

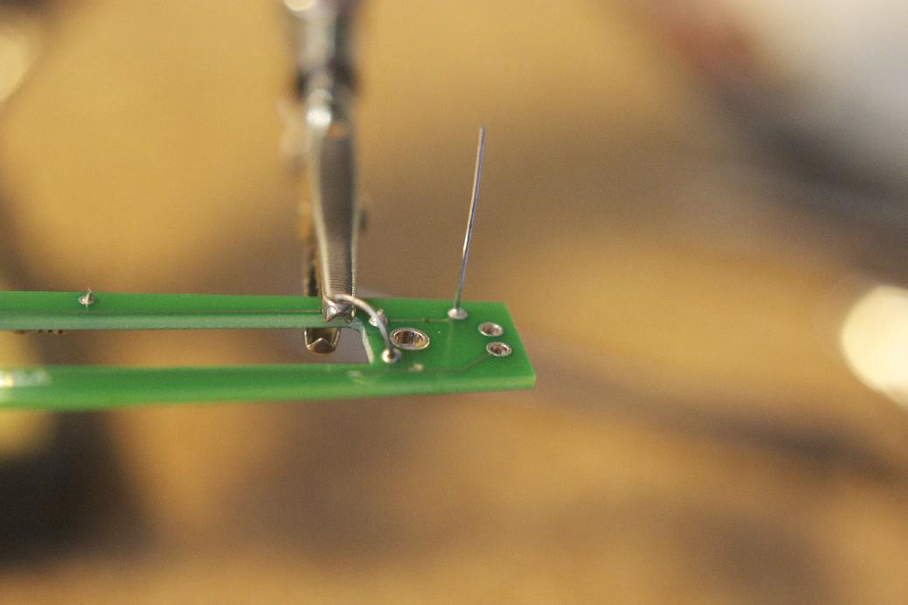
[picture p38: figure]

11: Sensor de fuerza resistivo

Localice el sensor de fuerza FSR. Tiene la apariencia de una faja de plástico con un círculo en uno de los extremos, y dos pequeños terminales en el otro.

Es un componente delicado, así que tenga cuidado cuando lo maneje para no retorcerlo o doblarlo demasiado. Al estar hecho de plástico, tenga especial cuidado al soldar para no derretirlo. Por esta razón es aconsejable utilizar un hemostato o un "cocodrilo" en el extremo de los terminales, de manera que además de mantenerlo en su posición para el soldado, ejerza la función de disipador de calor.

Desde la "cara de resistencias" inserte los dos terminales del FSR en los orificios marcados como "Sen1". Suelde desde el lado opuesto de la placa los terminales intentando ser rápido para evitar el peligro de derretir el sensor. El sensor debe quedar como se observa en la figura. El sensor no tiene polaridad por lo que no es relevante hacia donde mire, ya que mide fuerza por ambas caras.

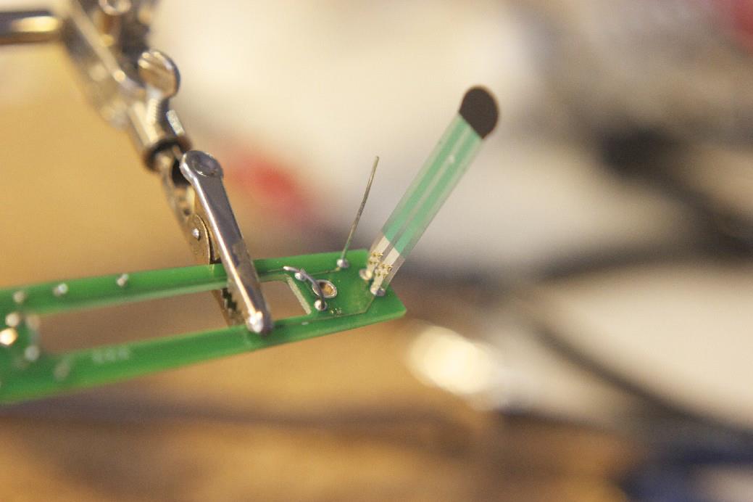
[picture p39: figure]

Llegado a este punto necesitará la carcasa para su PressurePen. Si aún no la tiene, puede adquirirla desde Shapeways - http://www.shapeways.com/shops/pressurepen - o imprimirla
en | una | impresora | 3D | descargando | los ficheros | STL | desde | Thingiverse | -
http://thingiverse.com/option8/

12: Montaje

Para los siguientes pasos, necesitara:

- Carcasa de plástico*
- Cinta adhesiva de doble cara
- Destornillador Torx T5 (estrella)

Sitúe la placa en la carcasa trasera (la mitad con orificios para el interruptor y el LED) con la "cara de la pila" mirando hacia usted. El interruptor y el LED debieran pasar por los orificios de la carcasa. En caso contrario, puede que sea necesario que lime o ensanche los orificios para que entren suavemente.

Con el destornillador T5, atornille la placa a la carcasa con los tres tornillos.

Corte una pequeña tira de cinta adhesiva de doble cara, la cinta fina y transparente, no la de espuma. Ponga este pedazo de cinta en la localización para el sensor, o en el sensor propiamente (ver figura) y cuidadosamente pegue el sensor a la carcasa como se muestra. Presione firmemente para que el sensor quede fijado, asegurándose de que queda centrado. Elimine el sobrante de cinta cuidadosamente.

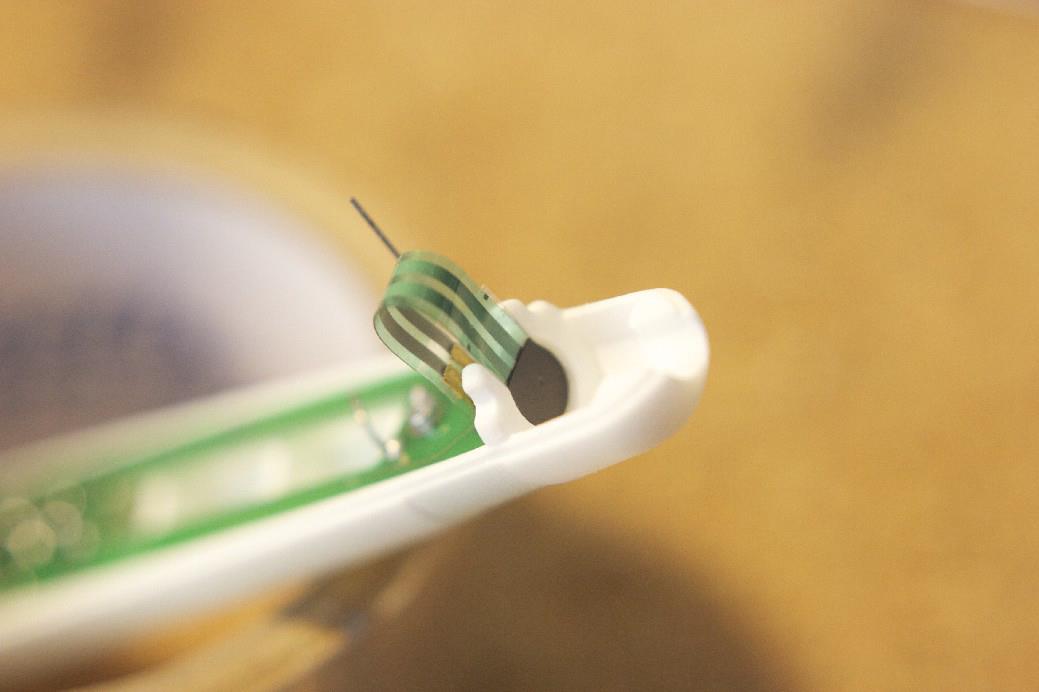
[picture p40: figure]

Localice el pequeño disco de espuma. Colóquelo encima del sensor en la cavidad en la punta de la carcasa.

Doble el cable de tierra (el terminal metálico soldado en el orificio GND) hacia la punta del puntero de manera que sobresalga por el pequeño agujero en la pared de plástico. Presione el cable firmemente dentro del disco de espuma para fijar el disco y conectar a tierra la punta. Corte o doble el exceso de cable para que no interfiera con el sensor.

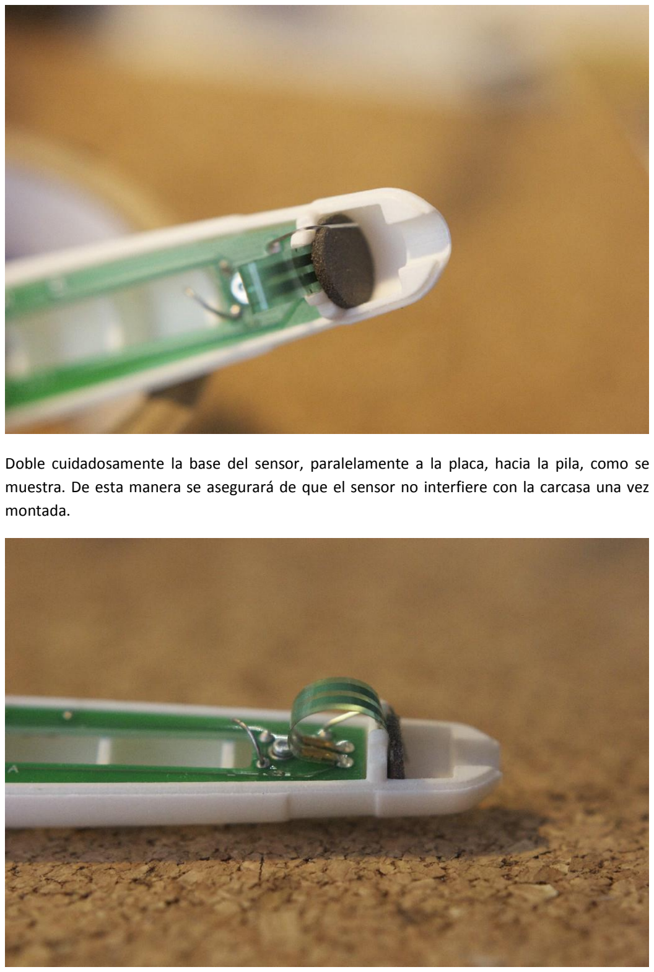
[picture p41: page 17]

Doble cuidadosamente la base del sensor, paralelamente a la placa, hacia la pila, como se muestra. De esta manera se asegurará de que el sensor no interfiere con la carcasa una vez montada.

13: Montaje de la punta conductora

La punta debiera tener un pequeño anillo alrededor de su eje, sobre un rebaje a tal efecto. Si el anillo se ha movido de este rebaje, colóquelo en su sitio. La punta encaja en el micropuntero. Puede ofrecer cierta resistencia, tendrá que apretar firmemente para que encajen ambas piezas.

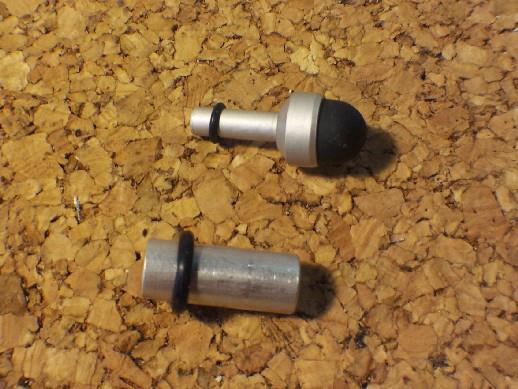
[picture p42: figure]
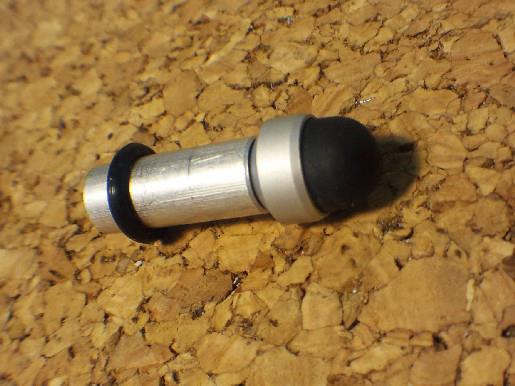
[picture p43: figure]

El micropuntero debe tener un anillo a su alrededor, que se mantiene en su lugar únicamente por fricción sin ningún rebaje. Introduzca el micropuntero en su lugar, asegurándose de que queda fijo con ayuda del anillo, de manera que el extremo del micropuntero opuesto a la punta quede en contacto con el sensor.

Dependiendo del origen de la carcasa que utilice, es posible que deba limar o agrandar el orificio para permitir que la punta del micropuntero se mueva libremente. Esto es esencial para que el puntero funcione debidamente. Para esto papel de lija de grano fino es lo más adecuado, envolviendo un tubo que quepa en el orificio.


14: Montaje final

Inserte una sola pila AAA en el compartimento.

Junte ambas mitades de la carcasa. La carcasa delantera tiene un orificio que encaja con el conector de audio, y mantiene el extremo trasero del PressurePen junto. Deslice la banda elástica por la punta y ajústela al rebaje a tal efecto. Su PressurePen está listo.

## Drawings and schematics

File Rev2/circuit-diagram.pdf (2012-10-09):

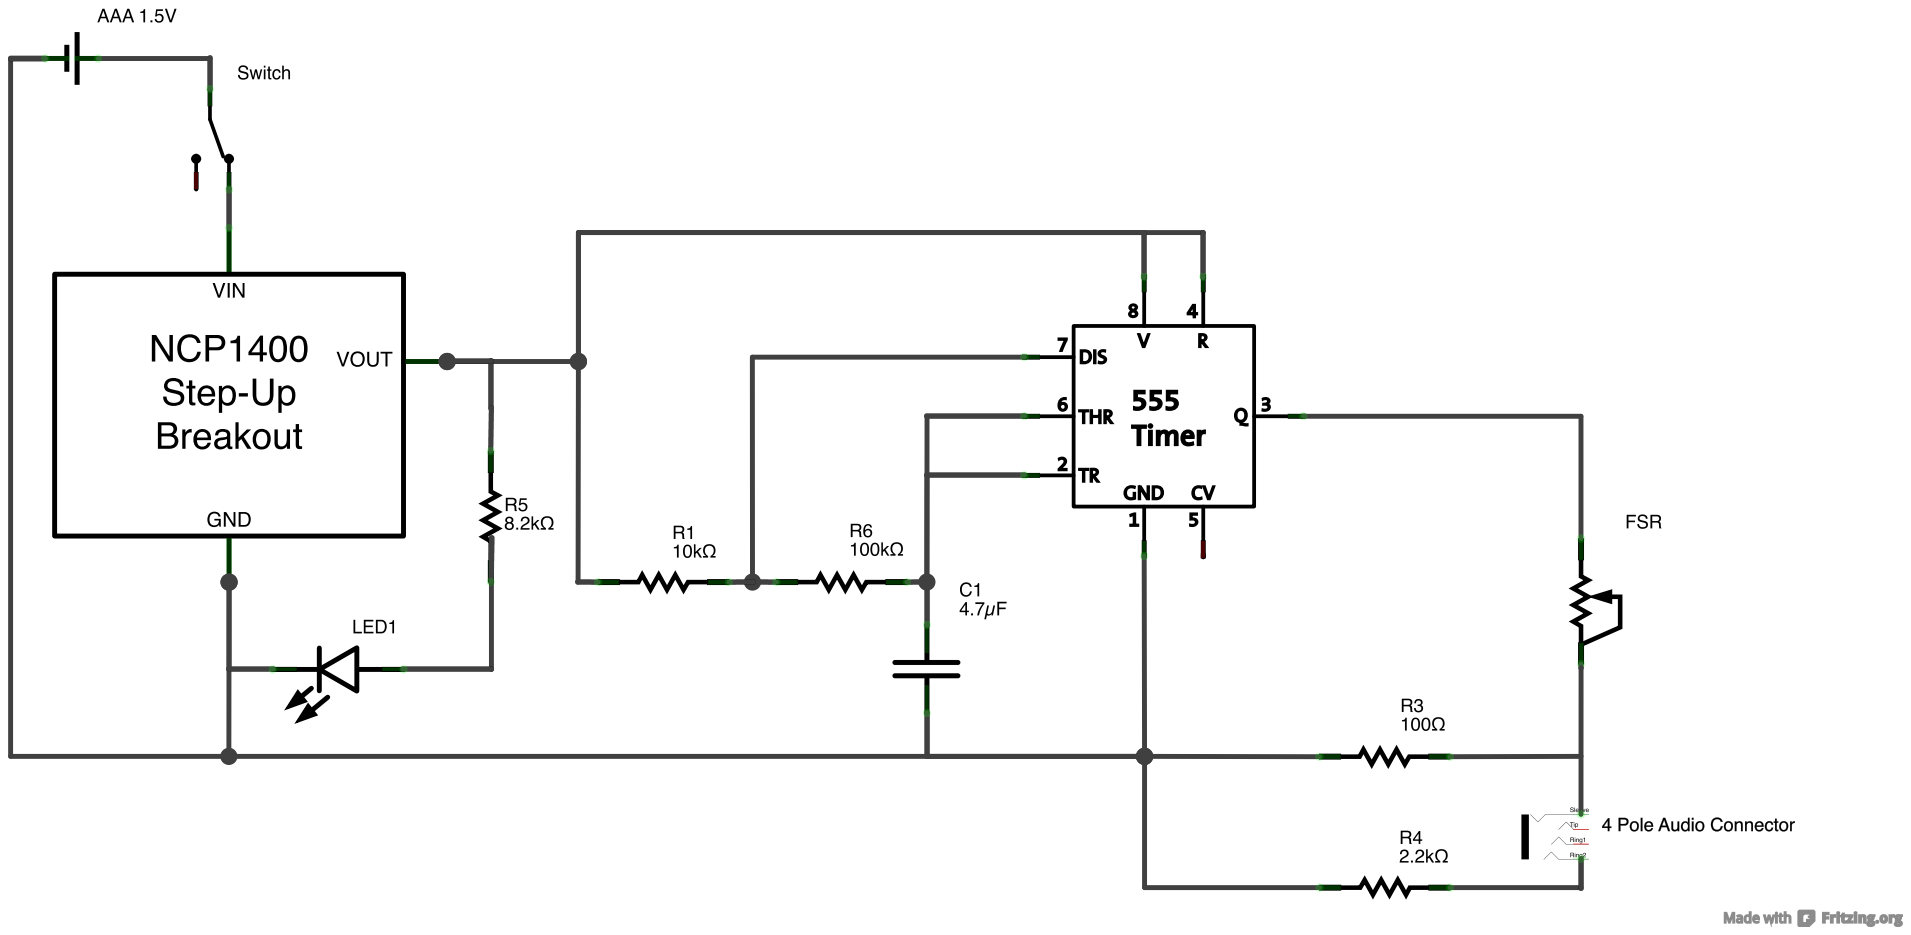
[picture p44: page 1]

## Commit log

2012-09-05 initial Rev2 BOM, readme
    [BOM.csv]
2012-09-05 added battery spring to BOM
    [BOM.csv]
2012-09-06 Added PCB Artist files for PressurePen board
    download the application here:
    http://www.4pcb.com/free-pcb-layout-software/index.html
2012-09-06 updated BOM quantities
    [BOM.csv]
2012-09-08 updated PCB
    notch added to accomodate audio jack
2012-09-09 added battery info to silkscreen
2012-09-10 added circuit diagram
2012-09-10 updated circuit diagram
    forgot the LED.
    aligned labels to PCB labels
2012-09-26 Assembly instructions
2012-10-09 Resistor R4 value change
    swaped R4 from 100Ω to 2.2kΩ for better device compatibility.
    [BOM.csv]
2012-10-24 Updated instructions
    Assembly instructions updated with new images, simplified grounding step
2013-01-04 updated BOM, part numbers
    [BOM.csv]
2013-03-02 plaintext version of assembly instructions
2013-03-02 Assembly instructions in Spanish
    Spanish translation by Guillermo Asín.
2013-12-19 added 3D files for shell parts
    [OP8_body_r12c_AA-Final.stp, OP8_body_r12c_AB-Final.stp]
